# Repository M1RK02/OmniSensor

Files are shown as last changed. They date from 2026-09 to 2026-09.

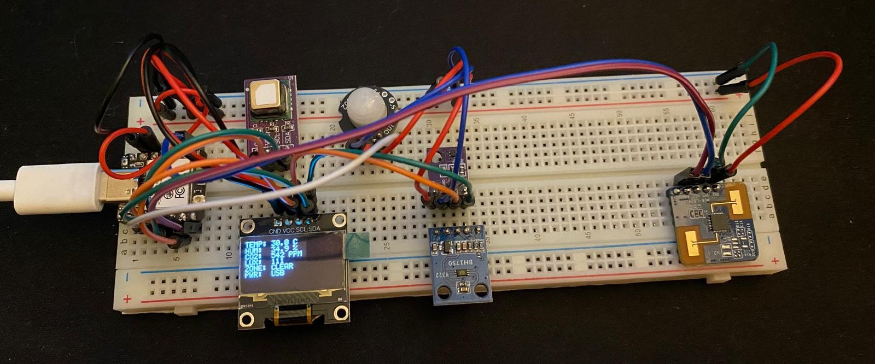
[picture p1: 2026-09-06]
docs/images/prototype_assembly.jpeg

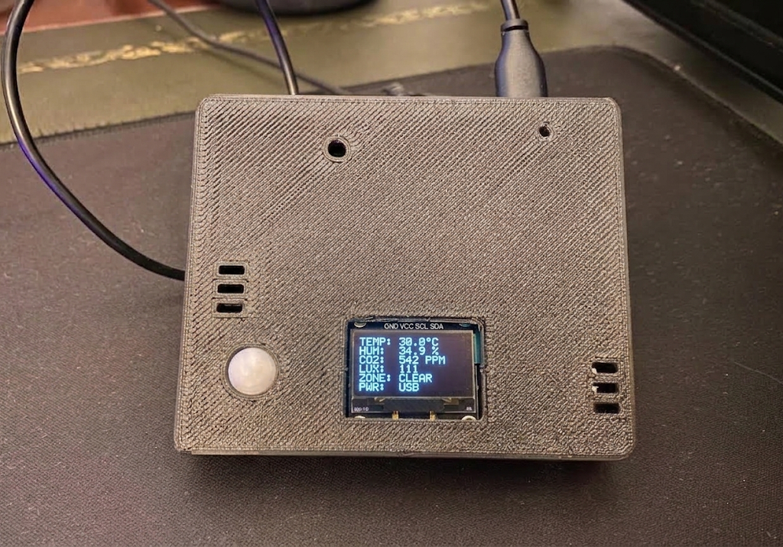
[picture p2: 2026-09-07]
docs/images/enclosure_assembly.png

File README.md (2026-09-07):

# OmniSensor

**A battery-powered, multi-zone presence and air-quality sensor — Matter over Thread, built on the Seeed Studio XIAO ESP32-C6.**

OmniSensor packs seven sensing devices into a single low-power node. It reports temperature, humidity,
CO₂ and ambient light to any Matter ecosystem (Apple Home, Home Assistant, Google Home) while a PIR and a
24 GHz mmWave radar work together to detect *where* in a room someone is — not just whether the room is
occupied. A local OLED shows the current readings without needing a phone.

The design target is a device that spends almost all of its life in deep sleep, drawing single-digit
microamps, and wakes instantly when someone walks in.

---

## Hardware

| Part | Function | Interface | Address / Pin |
|---|---|---|---|
| Seeed XIAO ESP32-C6 | MCU — RISC-V, Wi-Fi 6, 802.15.4 (Thread) | — | — |
| Sensirion SHT40 | Temperature + humidity | I²C | `0x44` |
| Sensirion SCD41 | CO₂ (photoacoustic NDIR) | I²C | `0x62` |
| ROHM BH1750 | Ambient light (lux) | I²C | `0x23` |
| SSD1315 | 128×64 monochrome OLED | I²C | `0x3C` |
| Hi-Link LD2420 | 24 GHz mmWave presence radar | UART | TX 16 / RX 17 |
| SR602 | PIR motion (deep-sleep wake source) | GPIO | `GPIO_NUM_2` |
| Diodes Inc. DMP2004K / SI2301 | P-MOSFET radar power switch | GPIO | D3 (GPIO21) |
| BOOT button | Factory reset + refresh | GPIO | GPIO9 (on-module) |

Shared I²C bus on **SDA 22 / SCL 23**. Full pin map and electrical design in
[project_description.md](project_description.md) and [docs/HARDWARE_DESIGN.md](docs/HARDWARE_DESIGN.md).

## Repository layout

```
OmniSensor/
├─ firmware/
│  ├─ hub/                  # integrated OmniSensor firmware (Matter over Thread)
│  └─ examples/             # standalone, one-sensor-at-a-time validation projects
│     ├─ sr602/             # PIR + GPIO deep-sleep wakeup
│     ├─ sht40/             # temperature + humidity, CRC checked
│     ├─ bh1750/            # ambient light
│     ├─ scd41/             # CO2 single-shot measurement
│     ├─ ld2420/            # mmWave radar over UART
│     ├─ ssd1315/           # OLED bring-up
│     └─ all/               # all seven together, with RTC-memory fast wake
├─ hardware/
│  ├─ altium/               # Altium Designer project files (.PrjPcb, .SchDoc, .PcbDoc, .OutJob)
│  ├─ datasheets/           # component reference sheets
├─ enclosure/               # 3D-printable enclosure CAD source and printable meshes
│  ├─ cad/                  # Autodesk Fusion archive (.f3d) and universal STEP (.step)
│  └─ stl/                  # sliced/printable STL meshes (front_shell.stl, rear_shell.stl)
└─ docs/                    # technical delivery report, software architecture, hardware design
```

## Quick start

Requires **ESP-IDF v5.4.3** targeting `esp32c6`. Full toolchain setup — including the Matter SDK —
is in [docs/SOFTWARE_DESIGN.md](docs/SOFTWARE_DESIGN.md).

```bash
get_idf                                   # activates ESP-IDF (alias, see docs/SOFTWARE_DESIGN.md)
cd firmware/examples/all
idf.py set-target esp32c6
idf.py build flash monitor
```

Each example under `firmware/examples/` is a self-contained ESP-IDF project and builds the same way.
Start with `sht40` if you just want to confirm your toolchain and wiring work.

## Documentation

| Document | Contents |
|---|---|
| [docs/DELIVERY_REPORT.pdf](docs/DELIVERY_REPORT.pdf) ([Typst](docs/DELIVERY_REPORT.typ)) | **Final Delivery & Technical Engineering Report** (architecture, PCB, firmware, testbed, power calculations) |
| [project_description.md](project_description.md) | Full technical description: architecture, BOM, pin map, power budget, Matter mapping |
| [docs/SOFTWARE_DESIGN.md](docs/SOFTWARE_DESIGN.md) | Firmware architecture, concurrency, presence/sensor subsystems, Matter model, and setup guide |
| [docs/HARDWARE_DESIGN.md](docs/HARDWARE_DESIGN.md) | Power management, load switching, battery sensing, PCB design and layout |

## References

* [Seeed Studio XIAO ESP32-C6 Wiki](https://wiki.seeedstudio.com/xiao_esp32c6_getting_started/)
* [ESP-Matter SDK Documentation](https://docs.espressif.com/projects/esp-matter/en/latest/esp32/)
* [ESP-IDF Programming Guide (ESP32-C6)](https://docs.espressif.com/projects/esp-idf/en/v5.4.3/esp32c6/)

## Contact

Contributions, questions and suggestions are welcome — send me an
[email](mailto:picamirko02@gmail.com).

## License

Released under the MIT license. See [LICENSE](LICENSE).

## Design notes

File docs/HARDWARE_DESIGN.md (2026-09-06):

# Hardware Design & Power Management

**Engineering Documentation · OmniSensor Carrier Board & Power Architecture**
Platform: Seeed Studio XIAO ESP32-C6 (single-core RISC-V)

This is the detailed engineering companion to [`../project_description.md`](../project_description.md).
Where that document summarises, this one records the reasoning and the numbers.

---

## 0. PCB design vs. wired prototype

Read this first, or the rest of the document is misleading.

The project produces **two hardware artifacts**, and only one of them physically exists:

| | PCB | Wired prototype |
|---|---|---|
| **Status** | Designed in Altium, ready for fabrication | Built and running |
| **Lives in** | `hardware/altium/`, `hardware/outputs/` | `docs/images/prototype_assembly.jpeg` |
| **Purpose** | Documented design deliverable & production release | The unit that gets demonstrated and measured |
| **Contains** | Every design decision below, laid out in copper | All sensors cabled to the always-on 3V3 rail; the load switch and battery divider exist in the PCB design and firmware only |

There was not enough time in the schedule for board fabrication and shipping, so the decision was made
early to treat the PCB as a design exercise and build the working unit with cables. Crucially, the
load switch and battery divider exist in the Altium PCB design and are implemented in firmware.
Sleep current and battery longevity figures are modeled in detail in [docs/DELIVERY_REPORT.pdf](DELIVERY_REPORT.pdf).

Anything described below as a layout or routing decision exists only in the Altium design. Anything
described as a measurement comes from the wired unit.

---

## 1. Firmware and power architecture

### Operating system

FreeRTOS, single-core. The Matter/Thread stack runs at high priority; the sensor, UI and battery tasks
run at medium-low priority so they cannot block the CPU and trip the Task Watchdog Timer.

This is not a theoretical concern. The SCD41 single-shot measurement takes roughly **5 seconds**. A
sensor task running at or above the network stack's priority would starve it for that entire window.

### Deep sleep — Sleepy End Device

The device operates as a Matter **SED** to maximise energy efficiency. The radio stays off most of the
time, waking periodically to poll the Border Router for queued messages.

Two events break that cycle and cause an **immediate** GPIO wake, followed by an unsolicited push of data
to the Thread network:

- presence detected by the PIR (or, once running, the mmWave radar)
- a physical button press

### RTC shared memory

State is preserved across deep sleep using `RTC_DATA_ATTR`. Sensor readings and system state are written
there before sleeping.

On wake, the ESP32-C6 performs a software reset and re-enters `app_main`. In that early phase the code is
still effectively **single-threaded** — the FreeRTOS scheduler is not yet doing anything interesting — so
the last known values can be read straight out of RTC memory and pushed to the OLED with no locking at
all. The user sees populated data instantly, instead of staring at a blank screen for the 5 seconds the
CO₂ sensor needs.

This is the whole reason the OLED sits on the always-on rail rather than the switched one.

### Concurrency and deadlock prevention

Once the FreeRTOS tasks are running, the free ride ends and shared memory access must be genuinely
thread-safe. Two approaches, in order of preference:

1. **Single-writer via queues (preferred).** Sensor and battery tasks publish readings onto a FreeRTOS
   queue; exactly one owner task performs every write to shared state. This removes the possibility of a
   deadlock rather than managing it.
2. **Mutexes with timeouts.** Where a mutex is unavoidable, it is always taken with a finite timeout,
   never `portMAX_DELAY`, so a stall surfaces as a logged error instead of a silent hang.

---

## 2. Load switching — sensor rail power

**Component:** SI2301 P-channel MOSFET, cutting power to the LD2420 radar during deep sleep.

### Fail-safe default (the important part)

The gate is held by an **external pull-up resistor**. A P-channel MOSFET with its gate pulled up to the
source is **off**.

This matters because the ESP32-C6 control pin does not always drive a defined level. During boot, after a
firmware crash, and throughout deep sleep when the GPIO drivers are powered down, that pin floats. With a
pull-down-biased design, a float could leave the sensor rail energised and quietly flatten the battery
over days with nobody noticing.

The rule applied here: **failure modes should fail toward low power.** A floating control pin costs a
missed reading, not a dead battery.

The SHT40 (~0.08 µA idle) and BH1750 (~0.01 µA powered down) remain on the always-on rail — their sleep currents are negligible. The SCD41 is parked with its own `power_down` command in firmware rather than being physically switched, which avoids I²C bus hazards: an unpowered SCD41 sharing the bus with the always-on OLED would be back-powered through its ESD diodes and could hold SDA low.

### Inrush stabilisation

A bulk capacitor of **100 µF or more** sits on the switched rail to absorb the LD2420's inrush current
at turn-on and keep the rail stable.

---

## 3. Battery monitoring (ADC)

### Voltage divider

Two **100 kΩ** resistors in series: V<sub>batt</sub> → ADC pin → GND.

The value is chosen for **leakage, not accuracy**. At a full charge of 4.2 V the divider continuously
bleeds:

```
I = 4.2 V / 200 kΩ ≈ 21 µA
```

That is the same order of magnitude as the entire target sleep current, which is precisely why it cannot
go any lower in resistance. Smaller resistors would give a stiffer source and a marginally better reading
while costing far more current — a bad trade for a battery device.

### Reading stabilisation

A **100 nF** capacitor is placed in parallel with the low-side (shunt) resistor.

The ESP32-C6's ADC uses a sample-and-hold capacitor that draws a brief charge current at the moment of
sampling. Driven directly from a 50 kΩ Thévenin source, that charge transfer would not settle within the
sampling window and every reading would come out low. The 100 nF acts as a local charge reservoir.

### ADC configuration

Internal attenuation is set to **−12 dB**, giving a usable input range up to roughly 3.1–3.3 V.

The divider halves the LiPo's maximum 4.2 V down to **2.1 V**, which places the reading in the middle of
the ADC's transfer curve — its most linear region — rather than compressed against either end.

### Software and calibration

- Use the **`esp_adc_cal`** API to apply the per-chip calibration values Espressif burns into the
  ESP32-C6's eFuses at manufacture. Raw ADC counts on this family are not accurate enough without them.
- Take an average of **32–64 readings** (multisampling).
- Perform that sampling **immediately after wake and before the Thread radio is enabled**. RF activity
  couples measurable noise onto the ADC input; sampling before the radio starts avoids the problem
  entirely rather than trying to filter it afterwards.

### Measured results

> **Projected values.** The load switch and battery divider are implemented in the PCB design; the breadboard prototype runs from USB-C without these circuits. The figures below are projections from datasheet values.
>
> | Measurement | Target | Measured |
> |---|---|---|
> | Deep sleep current, sensor rail off | 7–10 µA | projected |
> | Active current, all sensors powered | — | projected |
> | Divider reading vs. multimeter, 4.2 V | ±1 % | projected |
> | Divider reading vs. multimeter, 3.3 V | ±1 % | projected |

---

## 4. Layout and thermal isolation

*(Altium design only — not fabricated.)*

The environmental sensors are physically isolated from the XIAO ESP32-C6 module on the PCB. The module is
the dominant heat source on the board: the radio, the regulator and the CPU all sit inside it.

Two mitigations:

- **Physical separation.** The SHT40 and SCD41 are placed as far from the module as the outline allows.
- **Copper relief.** Milled slots and thermal cut-outs in the copper pour surround the temperature and
  humidity sensors, breaking the conduction path through the board itself. Copper is an excellent thermal
  conductor, which is exactly the problem here — without relief slots, the ground pour delivers the
  radio's waste heat straight to the sensor that is trying to measure room temperature.

A temperature sensor reading its own PCB's self-heating is worse than useless, because the error is
systematic and looks plausible.

Also specified in the layout:

- **External I²C pull-ups.** The current examples rely on the ESP32-C6's internal pull-ups. Those are
  weak — tens of kΩ — and marginal for a four-device bus with any meaningful trace capacitance. The PCB
  specifies proper external resistors. Final values depend on measured bus capacitance.
- **Decoupling.** Local ceramic capacitors at each device, plus the 100 µF+ bulk on the switched rail.

---

## 5. mmWave radar — gate logic

The LD2420 reports detection strength per distance **gate**. Gates are grouped into 0.7 m sectors to give
zone-based presence:

| Zone | Distance | Meaning |
|---|---|---|
| Zone 1 | < 0.7 m | At the device |
| Zone 2 | 0.7 – 1.4 m | Near field |
| Zone 3 | > 1.4 m | Room presence |

Each gate needs its **own sensitivity threshold**, because return signal strength falls off sharply with
distance — a single global threshold would either miss distant targets or produce constant false
positives up close. The Milestone 3 calibration routine tunes these against an empty room.

### Why two presence sensors

They are not redundant; they do different jobs:

| | SR602 (PIR) | LD2420 (mmWave) |
|---|---|---|
| Detects | Motion | Presence, including stationary |
| Distance | No | Yes, per gate |
| Power | Negligible | Needs the sensor rail up |
| Can wake from deep sleep | **Yes**, via GPIO | No |
| Role | **Trigger** | **Qualifier** |

The PIR wakes the device. The radar then determines which zone is occupied and holds occupancy true while
a motionless person remains — the exact case a PIR alone gets wrong, and the reason PIR-only lights
switch off on people sitting still.

---

## 6. Matter integration

Presence events and environmental data map onto standard Matter clusters, handled natively by the
ESP-Matter SDK. Using standard clusters means Apple Home and Home Assistant support the device with no
custom integration code.

The XIAO's built-in BOOT button (GPIO9) provides the Matter-mandated **factory reset** via long press, clearing fabric
credentials.

Occupancy Sensing carries a standard boolean presence state. Exposing granular multi-zone distance information can be achieved via multiple sub-endpoints or a custom cluster.

---

## 7. Enclosure integration

- **PIR Fresnel lens.** A dedicated holder positions the lens at its designed focal distance from the
  pyroelectric element. This is not adjustable after the fact: get the spacing wrong and detection range
  collapses, with no obvious symptom other than poor sensitivity.
- **mmWave mounting.** The radar is mounted **flush** with the case wall. Plastic in the beam path
  produces internal reflections that the radar reports as phantom targets — ghosting that would corrupt
  the zone logic with detections that never move.
- **SCD41 airflow.** Vents provide genuine air exchange with the room. A CO₂ sensor in a sealed
  enclosure measures the enclosure. Vent placement must also avoid drawing XIAO-warmed convection air
  across the SHT40.
- **Internal volume.** Sized for cabling, since the internals are a wired prototype rather than a flat
  PCB assembly.

---

## 8. Exporting from Altium

Keep the repository tidy and reviewable:

1. Export gerbers, drill files, BOM, STEP 3D model, and schematic PDF into **`hardware/outputs/`** via an OutJob so the outputs are reproducible.
2. The **PDF of the schematic** and **Gerber/STEP files** in `hardware/outputs/` allow the design to be reviewed by anyone without an Altium licence.
3. Do not commit Altium's `History/` folder. It accumulates large zip blobs and is already excluded in
   `.gitignore`.

> **Note on line endings.** `.SchDoc` and `.PcbDoc` are OLE compound binary files. The repository's
> `.gitattributes` marks them `binary` so Git never attempts line-ending conversion or a three-way merge
> on them — either would corrupt the file silently. This matters here because Altium runs on the Windows
> host while the repository lives in WSL. Do not remove those rules.

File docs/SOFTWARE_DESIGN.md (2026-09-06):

# Software Design & Architecture

**Engineering Documentation · OmniSensor Hub Firmware**  
Platform: Seeed Studio XIAO ESP32-C6 (Single-core RISC-V, 160 MHz)  
Operating System: FreeRTOS (ESP-IDF v5.4.3)  
Application Framework: ESP-Matter (Matter 1.3 / OpenThread)  
Device Role: Matter Sleepy End Device (SED) over Thread  

---

## 1. System Overview & Philosophy

OmniSensor operates as an ultra-low-power, multi-sensor environment and presence node. The software is engineered around three core constraints:

1. **Energy Scarcity:** The node is designed for battery operation. Sensors cannot stay continuously powered, and the ESP32-C6 must spend the vast majority of its life in deep sleep.
2. **Single-Core Concurrency:** The RISC-V core must run the high-priority OpenThread/Matter network stack alongside long sensor conversions (e.g. 5 seconds for the SCD41 CO₂ sensor), local display rendering, and UART radar frame parsing without tripping the Task Watchdog Timer (TWDT).
3. **Instantaneous UI Responsiveness:** When a user walks up to the device, the local OLED must display populated sensor readings in milliseconds rather than waiting 5 seconds for a sensor conversion or several seconds for network reconnection.

```mermaid
graph TD
    subgraph Drivers["Sensor & Hardware Drivers"]
        PIR["SR602 (PIR)"]
        RADAR["LD2420 (mmWave Radar)"]
        ENV["SHT40 / SCD41 / BH1750"]
        BATT["Battery ADC (VBAT)"]
        BTN["BOOT Button (GPIO9)"]
    end

    subgraph Producers["FreeRTOS Producer Tasks"]
        T_PRES["Presence Task<br/>(PIR + Radar Fusion)"]
        T_SENS["Sensor Task<br/>(Periodic / Refresh)"]
        T_BATT["Battery Task<br/>(Low Frequency)"]
    end

    subgraph Core["State Management"]
        Q["omni_event_queue()<br/>(Thread-Safe Queue)"]
        OWNER["State Owner Task<br/>(app_main.cpp)"]
        STATE["g_state (Shared State)"]
        RTC["RTC Fast Memory<br/>(Survives Deep Sleep)"]
    end

    subgraph Consumers["Consumers & Output"]
        MATTER["ESP-Matter / OpenThread<br/>(Endpoints 1-5 Clusters)"]
        UI["Display Task<br/>(SSD1315 OLED)"]
    end

    PIR --> T_PRES
    RADAR --> T_PRES
    ENV --> T_SENS
    BATT --> T_BATT
    BTN --> OWNER

    T_PRES -->|OMNI_EVT_PRESENCE| Q
    T_SENS -->|OMNI_EVT_ENV| Q
    T_BATT -->|OMNI_EVT_BATTERY| Q

    Q --> OWNER
    OWNER --> STATE
    OWNER --> RTC
    OWNER --> MATTER
    OWNER --> UI
```

---

## 2. Concurrency Model: Actor / Single-Writer Pattern

### The Problem
On a single-core microcontroller, standard multi-threaded code that shares memory using mutexes is prone to priority inversion, high latency, and deadlocks. Furthermore, blocking transactions (such as the 5-second photoacoustic conversion of the Sensirion SCD41) would starve the network stack if executed in the wrong context.

### The Architecture
OmniSensor strictly adheres to a **single-writer actor pattern**:
* **Producers:** Sensor tasks, presence tasks, and battery tasks act exclusively as producers. They collect raw data, validate checksums (CRC-8), format an `omni_evt_t` structure, and push it onto the non-blocking FreeRTOS queue `omni_event_queue()`.
* **The Single Writer:** Exactly **one** task — the state owner in `firmware/hub/main/app_main.cpp` — reads from `omni_event_queue()`. It is the only entity permitted to write to `g_state` and push cluster attribute reports to the Matter data model.
* **Non-Blocking Ingress:** Calls to `omni_post_event()` never block longer than 1 FreeRTOS tick. If the queue is full under heavy load, the event is dropped and logged with `ESP_ERR_TIMEOUT`. A dropped measurement is vastly preferable to a stalled producer.

### Task Priority Hierarchy

All application task priorities sit strictly below the Matter/OpenThread stack:

| Priority | Task Name | Function | Rationale |
|---|---|---|---|
| **5+** | `Matter/OpenThread` | Mesh packet processing, crypto, network maintenance | Network packets must never be delayed by sensor tasks |
| **4** | `State Owner` (`app_main`) | Dequeues events, updates `g_state`, reports to Matter clusters | Highest application priority to promptly clear the event queue |
| **3** | `omni_sensor` | SHT40, SCD41, BH1750 sequencing | Runs long I²C transactions without starving the system |
| **3** | `omni_presence` | LD2420 UART parsing & PIR GPIO monitoring | Processes 24 GHz presence frames in real time |
| **3** | `omni_ui` | SSD1315 OLED rendering | Refreshes UI on state changes without blocking sensing |
| **2** | `omni_battery` | ADC multisampling & battery curve lookup | Runs rarely (every 10 minutes) at lowest priority |

---

## 3. Presence Sensing Subsystem (PIR + mmWave Fusion)

OmniSensor fuses two complementary technologies to eliminate the classic flaws of single-technology motion sensors:

```
  ┌───────────────┐               ┌────────────────┐
  │  SR602 (PIR)  │               │ LD2420 (Radar) │
  └───────┬───────┘               └───────┬────────┘
          │ Gross motion (< 10 ms)        │ Stationary breathing & range
          ▼                               ▼
     [Wake Trigger] ─────────────► [Qualifier / Gate Evaluator]
          │                               │
          └───────────────┬───────────────┘
                          ▼
             Fused Occupancy State & Zone
```

### 1. SR602 PIR (The Trigger)
* **Interface:** GPIO2 (`OMNI_PIN_PIR`), active HIGH.
* **Characteristics:** Extremely low quiescent current (< 20 µA), analog pyroelectric detection.
* **Role:** Instantaneous trigger (< 10 ms). When the device is in deep sleep, only the PIR (and the BOOT button) remains configured as an external wake-up source (`esp_sleep_enable_ext0_wakeup`). It awakens the ESP32-C6 when gross motion occurs.

### 2. HLK-LD2420 24 GHz Radar (The Qualifier)
* **Interface:** UART0 (TX GPIO16, RX GPIO17) running at 256,000 baud.
* **Power Control:** Switched rail `+3V3_SW` controlled via P-channel MOSFET `Q1` (GPIO21 / `OMNI_PIN_RAIL_EN`, active LOW).
* **Operation:**
  * When awake, the radar continuously emits 24 GHz FMCW signals and reports energy across multiple distance **gates** (each gate ≈ 0.70 m).
  * The firmware maps these gates into three distinct distance zones:
    * **Zone 1:** $< 0.7\text{ m}$ (At the device / desk interaction)
    * **Zone 2:** $0.7\text{ m} - 1.4\text{ m}$ (Near field)
    * **Zone 3:** $> 1.4\text{ m}$ (Room presence)
* **Why Fusion Matters:** A PIR cannot detect a human sitting still reading a book or working at a computer, leading to false "empty room" timeouts. The LD2420 detects micromovements down to breathing. The PIR wakes the system; the radar confirms presence and keeps occupancy active even when motionless.

---

## 4. Environmental Sensing Subsystem

The sensor task (`firmware/hub/main/sensor_task.c`) manages the shared I²C bus (`SDA` GPIO22, `SCL` GPIO23) using the modern ESP-IDF `driver/i2c_master.h` driver:

### 1. Sensirion SHT40 (Temperature & Humidity)
* **Address:** `0x44`
* **Operation:** High-precision mode (`0xFD`), takes ~8 ms conversion time.
* **Reliability:** 6-byte response (Temp MSB/LSB + CRC8, Humidity MSB/LSB + CRC8) verified against polynomial $0x31$ ($x^8 + x^5 + x^4 + 1$).

### 2. ROHM BH1750 (Ambient Light)
* **Address:** `0x23` (ADDR pin grounded).
* **Operation:** Continuously sampled or high-resolution one-shot mode (1 lx resolution, 120 ms integration).
* **Conversion:** Raw 16-bit count divided by 1.2 yields calibrated lux.

### 3. Sensirion SCD41 (Photoacoustic NDIR CO₂)
* **Address:** `0x62`
* **Current Profile:** Photoacoustic infrared heating pulses draw up to 200 mA peak.
* **Single-Shot Low-Power Mode:** Rather than running continuous measurement (~15–20 mA average), the firmware uses single-shot mode (`measure_single_shot`, command `0x219D`). The sensor measures for 5 seconds and returns results.
* **Bus Back-Powering Prevention:** To save power between readings, the SCD41 is issued a software `power_down` command (`0x36E0`) rather than disconnecting its power rail. An unpowered I²C chip sharing lines with an always-on bus would be back-powered through its internal ESD protection diodes, corrupting the bus.
* **Interval Bounding:** To prevent frequent motion wakes from flattening the battery via repeated 5-second CO₂ runs, the firmware enforces a 120-second cooldown (`OMNI_SCD41_MIN_INTERVAL_MS`).

---

## 5. Display & Fast-Wake UI (SSD1315 OLED)

* **Interface:** I²C `0x3C`, 128×64 monochrome OLED.
* **Rail:** Maintained on the always-on rail `+3V3_AO`.

### RTC Fast-Wake State Restoration
When waking from deep sleep, the ESP32-C6 performs a software reset and re-executes `app_main`. Without optimization, the display would remain blank for up to 5 seconds while the SCD41 completes conversion.

To solve this:
1. Prior to deep sleep, the state owner copies the last valid sensor readings into RTC Slow Memory using the `RTC_DATA_ATTR` attribute.
2. Immediately upon boot — while FreeRTOS is starting and before the network stack or sensors initialise — `display.c` reads the RTC cache and paints the screen in under **50 ms**.
3. The user sees populated numbers instantly upon walking up to the device.

---

## 6. Power Management & Battery ADC

### Battery Voltage Sensing (`power.c`)
The battery divider consists of two 100 kΩ 1% resistors connected directly to `VBAT`.
* **ADC Configuration:** ESP32-C6 ADC1 Channel 0 (GPIO0 / `OMNI_PIN_BATT_SENSE`) configured with $-12\text{ dB}$ attenuation ($0 - 3.3\text{ V}$ range).
* **Noise Mitigation:** RF transmission produces electromagnetic coupling onto high-impedance ADC lines. The battery sampling routine runs **immediately after wake and before the Thread radio is started**.
* **Multisampling & Calibration:** Takes 32–64 samples, applies factory eFuse calibration via `esp_adc_cal`, and averages.
* **Discharge Curve:** Translates calibrated millivolts ($3.0\text{ V} - 4.2\text{ V}$) to state-of-charge percentage via an empirical LiPo discharge lookup table (`k_batt_curve`).

### Light Sleep Lock Management
During active bus transfers, ESP-IDF's automatic light sleep can shut down peripheral clocks, truncating I²C and UART bytes. The firmware implements reference-counted sleep holds via `omni_stay_awake(bool hold)`.

---

## 7. Matter over Thread Integration

The device integrates with the **ESP-Matter SDK** (built on the official CSA Matter specification):

### Matter Data Model & Cluster Mapping

| Endpoint | Cluster | Device Type | Reported Attributes |
|---|---|---|---|
| **0** | Basic Information, Thread Network Diagnostics, General Commissioning | Root Node | Device Name, Vendor ID, Product ID, Firmware Version |
| **1** | Temperature Measurement (`0x0402`) | Temperature Sensor | `MeasuredValue` (scaled $0.01^\circ\text{C}$) |
| **2** | Relative Humidity Measurement (`0x0405`) | Humidity Sensor | `MeasuredValue` (scaled $0.01\%$) |
| **3** | Illuminance Measurement (`0x0400`) | Light Sensor | `MeasuredValue` ($10000 \times \log_{10}(\text{lux}) + 1$) |
| **4** | Carbon Dioxide Concentration (`0x040D`) | Air Quality / CO₂ | `MeasuredValue` (parts per million ppm) |
| **5** | Occupancy Sensing (`0x0406`) | Occupancy Sensor | `Occupancy` (Bitmap / Boolean presence) |

### On-Board BOOT Button (GPIO9)
The XIAO's built-in BOOT button handles dual roles:
* **Short Press (< 2 s):** Wakes the UI and triggers an immediate sensor refresh.
* **Long Press (> 5 s):** Initiates a Matter factory reset, clearing Thread network credentials and entering commissioning mode.

---

## 8. Standalone Validation Suite (`firmware/examples/`)

During initial sensor bring-up, each sensor driver was developed and verified in isolation under `firmware/examples/` before being integrated into `firmware/hub/`. Every example is a self-contained ESP-IDF project:

| Example Project | Focus & Validation Criteria |
|---|---|
| `firmware/examples/sht40` | I²C communication at `0x44`, high-precision read, CRC-8 validation. |
| `firmware/examples/bh1750` | Lux calculation, integration time adjustment, bus compatibility. |
| `firmware/examples/scd41` | Photoacoustic single-shot timing, `power_down` command, rail droop check. |
| `firmware/examples/ld2420` | High-speed UART at 256k baud, binary frame parsing, gate energy detection. |
| `firmware/examples/sr602` | GPIO2 interrupt latency, low-power ext0 wake-up verification. |
| `firmware/examples/ssd1315` | I²C display initialization, 128×64 frame buffer, custom typography rendering. |
| `firmware/examples/all` | Simultaneous bus integration, RTC memory persistence across deep sleep. |

---

## 9. Development Environment & Setup Guide

### 1. Prerequisites

#### macOS
```bash
brew install cmake ninja dfu-util ccache python
```

#### Debian / Ubuntu / WSL2
```bash
sudo apt-get update
sudo apt-get install -y git wget flex bison gperf python3 python3-pip python3-venv \
                        cmake ninja-build ccache libffi-dev libssl-dev dfu-util libusb-1.0-0
```

### 2. Install ESP-IDF v5.4.3

```bash
mkdir -p ~/esp
cd ~/esp
git clone -b v5.4.3 --recursive https://github.com/espressif/esp-idf.git
cd esp-idf
./install.sh esp32c6
```

### 3. Install the ESP-Matter SDK (Required for `firmware/hub/`)

```bash
cd ~/esp
git clone --depth 1 https://github.com/espressif/esp-matter.git
cd esp-matter
git submodule update --init --depth 1
cd ./connectedhomeip/connectedhomeip
./scripts/checkout_submodules.py --platform esp32 linux --shallow
cd ../..
./install.sh --no-host-tool
```

### 4. Configure Shell Aliases
Add these aliases to `~/.bashrc` or `~/.zshrc`:

```bash
alias get_idf='export IDF_CCACHE_ENABLE=1 && source ~/esp/esp-idf/export.sh'
alias get_matter='get_idf && source ~/esp/esp-matter/export.sh'
```

### 5. Building & Flashing

#### Standalone Examples (ESP-IDF only):
```bash
get_idf
cd firmware/examples/sht40
idf.py set-target esp32c6
idf.py build flash monitor
```

#### Integrated Hub Firmware (ESP-Matter):
```bash
get_matter
cd firmware/hub
idf.py set-target esp32c6
idf.py build flash monitor
```

### 6. Matter Commissioning (Home Assistant / Apple Home)
1. Ensure your local network has an active **Thread Border Router** (e.g. Raspberry Pi 3B running Home Assistant with an ESP32-C6 OTBR RCP, Home Assistant Yellow/SkyConnect, Apple TV 4K, HomePod mini).
2. Run `idf.py monitor` on the hub firmware. The console will display the Matter QR-code link and manual pairing code.
3. In Home Assistant, navigate to **Settings → Devices & Services → Add Integration → Matter (Thread)**, scan the QR code, and complete commissioning.

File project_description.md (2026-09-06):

# OmniSensor — Project Description

**A battery-powered, multi-zone presence and air-quality sensor for Matter over Thread.**

| | |
|---|---|
| **Platform** | Seeed Studio XIAO ESP32-C6 (single-core RISC-V, Wi-Fi 6, 802.15.4) |
| **Protocol** | Matter over Thread, operating as a Sleepy End Device (SED) |
| **Toolchain** | ESP-IDF v5.4.3 + ESP-Matter SDK, target `esp32c6` |
| **Author** | Mirko Pica |
| **License** | MIT |
| **Deadline** | 8 September 2026 |

---

## 1. Abstract

Most commercial occupancy sensors answer a single yes/no question: is anyone in the room? OmniSensor
answers a more useful one — *where* in the room, and *what is the air like there*. It fuses a PIR motion
sensor with a 24 GHz mmWave presence radar to divide the space in front of it into 0.7 m distance bands,
and it pairs that with a CO₂, temperature, humidity and illuminance sensor package. Everything is exposed
to any Matter controller over a Thread mesh, and a small OLED shows the live readings locally.

The engineering challenge is not the sensing — it is doing all of this on a battery. A CO₂ sensor alone
can pull tens of milliamps while measuring. OmniSensor therefore spends nearly all of its life in deep
sleep with the entire sensor rail physically disconnected by a load switch, targeting a sleep current in
the **single-digit microamps**, and wakes within milliseconds when the PIR fires.

## 2. Goals

### Functional

- Report temperature, relative humidity, CO₂ concentration and illuminance as standard Matter clusters.
- Report occupancy, resolved into three distance zones rather than a single boolean.
- Wake instantly on physical presence and push an unsolicited update to the Thread network.
- Display current readings on a local OLED without requiring a phone or hub.
- Commission into Apple Home and Home Assistant using standard Matter flows.
- Provide a factory reset via long-press on the XIAO's built-in BOOT button (GPIO9).

### Non-functional

- Deep-sleep current low enough for a multi-month battery life on a single LiPo cell.
- Temperature and humidity readings unpolluted by self-heating from the radio.
- No data races on state shared between the sensing, UI and network tasks.
- UI must appear populated *immediately* on wake, not after the 5 s CO₂ measurement completes.

## 3. System architecture

```mermaid
graph TD
    subgraph MCU["XIAO ESP32-C6"]
        CPU["RISC-V core<br/>FreeRTOS"]
        RTCMEM["RTC memory<br/>(survives deep sleep)"]
        RADIO["802.15.4 radio<br/>Thread / Matter"]
    end

    subgraph SW["Switched radar rail (SI2301)"]
        LD["LD2420<br/>mmWave radar"]
    end

    subgraph AO["Always-on 3V3"]
        SHT["SHT40<br/>temp + humidity"]
        SCD["SCD41<br/>CO2"]
        BH["BH1750<br/>lux"]
    end

    OLED["SSD1315 OLED"]
    PIR["SR602 PIR"]
    BTN["BOOT button<br/>GPIO9"]
    BATT["LiPo + divider"]

    CPU -->|I2C SDA22/SCL23| SHT
    CPU -->|I2C| SCD
    CPU -->|I2C| BH
    CPU -->|I2C| OLED
    CPU -->|UART 16/17| LD
    PIR -->|GPIO2 wake| CPU
    BTN -->|GPIO9 wake| CPU
    BATT -->|ADC| CPU
    CPU -->|load switch GPIO| SW
    CPU <--> RTCMEM
    CPU <--> RADIO
```

Note that the OLED sits on the *always-on* rail, not the switched one, so the display can be refreshed
from RTC memory before the sensors have even powered up.

## 4. Bill of materials

| Part | Function | Interface | Address / Pin | Notes |
|---|---|---|---|---|
| Seeed XIAO ESP32-C6 | MCU, Wi-Fi 6 + Thread | — | — | Single-core RISC-V; on-board LiPo charger |
| Sensirion SHT40 | Temperature + humidity | I²C | `0x44` | ±0.2 °C; CRC-8 checked |
| Sensirion SCD41 | CO₂ (+ T/RH) | I²C | `0x62` | Photoacoustic NDIR; ~5 s single-shot; high inrush |
| ROHM BH1750 | Ambient light | I²C | `0x23` | ADDR to GND; 120 ms high-res conversion |
| SSD1315 | 128×64 OLED | I²C | `0x3C` | SSD1306-compatible command set |
| Hi-Link LD2420 | 24 GHz mmWave presence | UART | TX 16 / RX 17 | Gate-based distance reporting |
| SR602 | PIR motion | GPIO | `GPIO_NUM_2` | Deep-sleep wake source; needs Fresnel lens |
| Vishay SI2301 | P-MOSFET load switch | GPIO | D3 (GPIO21) | Cuts the sensor rail during sleep. Feeds LD2420 only |
| 2× 100 kΩ, 1× 100 nF | Battery ADC divider | ADC | D0 (GPIO0) | PCB design; see §7 |
| 100 µF+ | Switched-rail bulk cap | — | — | Absorbs LD2420 inrush at rail turn-on |

## 5. Pin map

| Signal | XIAO pin | Direction | Notes |
|---|---|---|---|
| I²C SDA | 22 | bidir | Shared by SHT40, SCD41, BH1750, SSD1315 |
| I²C SCL | 23 | out | 100 kHz for sensors, 400 kHz for the OLED |
| Radar UART TX | 16 | out | UART0; connects to module RX |
| Radar UART RX | 17 | in | UART0; connects to module TX |
| PIR | `GPIO_NUM_2` | in, pull-down | Deep-sleep wake, active HIGH |
| Sensor rail enable | D3 (GPIO21) | out | Active LOW (P-MOSFET gate); PCB pull-up to 3V3 |
| Battery sense | D0 (GPIO0) | analog | ADC1_CH0, −12 dB attenuation |
| BOOT button | GPIO9 | in | On-module; short press refreshes, long press factory reset |

## 6. Power management

The device operates as a **Matter Sleepy End Device**. The Thread radio is off for the vast majority of
the time, waking periodically to poll its parent router for queued messages. Two things break that
rhythm: a presence event from the PIR or radar, or a physical button press. Both are GPIO wake sources
that trigger an immediate wake and an unsolicited attribute report, so the network sees presence with no
polling latency.

### Load switching

Even in deep sleep, the sensors themselves would dominate the power budget — the SCD41 in particular. A
**SI2301 P-channel MOSFET** therefore cuts power to the radar (LD2420)
whenever the device sleeps. The SHT40 and BH1750 draw negligible idle current and remain on the always-on rail. The SCD41 is parked with its own power_down command in firmware rather than being physically switched, avoiding I²C bus hazards from an unpowered device sharing the bus with the always-on OLED.

The gate is held by an **external pull-up resistor**, which is a deliberate safety choice: a P-MOSFET
with its gate pulled to the source voltage is *off*. If the ESP32-C6 control pin floats — during boot,
after a firmware crash, or throughout deep sleep when GPIO drivers are powered down — the sensor rail
defaults to **off** rather than silently draining the battery. Failure modes should fail toward low
power, not away from it.

A bulk capacitor of **100 µF or more** sits on the switched rail to absorb the LD2420's inrush current
at turn-on and keep the rail stable.

### Wake sequence

1. GPIO wake fires. The ESP32-C6 performs a software reset and re-enters `app_main`.
2. Still single-threaded, before the FreeRTOS scheduler matters, the last known readings are pulled from
   RTC memory and pushed straight to the OLED. The user sees data immediately.
3. The sensor rail is switched on and the staggered warm-up begins.
4. The battery ADC is sampled — deliberately *before* the Thread radio comes up (see §7).
5. Tasks start, sensors are read, RTC memory and the OLED are refreshed, Matter attributes are reported.
6. After an inactivity timeout with no presence, the OLED is put to sleep, the rail is cut, and the
   device returns to deep sleep.

## 7. Battery monitoring

A resistive divider of **two 100 kΩ resistors** in series (V<sub>batt</sub> → ADC pin → GND) halves the
cell voltage. The value is chosen for leakage, not accuracy: at a full 4.2 V the divider bleeds only
about **21 µA**, which is the same order as the target sleep current and therefore acceptable. Lower
resistances would measure marginally better and cost far more current.

A **100 nF capacitor** across the low-side resistor gives the ADC's sample-and-hold something to charge
from. The ESP32-C6's ADC input impedance is high enough that, driven directly by a 50 kΩ Thévenin source,
the sampled value would read low.

The ADC runs at **−12 dB attenuation**, giving a usable range up to roughly 3.1 V. With the divider
halving 4.2 V down to 2.1 V, readings land in the middle of the ADC's most linear region rather than
against either rail. Calibration uses **`esp_adc_cal`**, which reads the per-chip correction values
Espressif burns into the eFuses at manufacture.

Sampling takes an **average of 32–64 readings**, performed immediately after wake and **before the Thread
radio is enabled**. RF activity couples measurable noise onto the ADC; sampling first sidesteps it
entirely rather than trying to filter it out afterwards.

## 8. Firmware architecture

The ESP32-C6 is single-core, so task priorities are a real design constraint rather than a formality.

| Task | Priority | Responsibility |
|---|---|---|
| Matter / Thread stack | High | Network stack, commissioning, attribute reporting |
| Sensor task | Medium-low | Sequenced I²C reads, radar UART parsing |
| UI task | Medium-low | OLED rendering |
| Battery task | Low | Periodic ADC sampling, multisampling average |

Sensor, UI and battery work runs **below** the Matter stack. The sensor path in particular contains long
blocking waits — the SCD41 needs roughly 5 s for a single-shot measurement — and running that at or above
the network priority would starve the stack and trip the Task Watchdog Timer.

### Shared state

Readings live in `RTC_DATA_ATTR` variables so they survive deep sleep. This is what makes the instant-UI
behaviour possible: on wake, `app_main` reads them while still effectively single-threaded, before task
concurrency exists, so no locking is needed at that point.

Once the scheduler is running, concurrency is real. The chosen approach is a **single writer**: sensor
and battery tasks publish readings onto a FreeRTOS queue, and one owner task performs every write to
shared state. This eliminates the deadlock question rather than managing it. Where a mutex is genuinely
needed instead, it is taken with a timeout — never `portMAX_DELAY` — so a stall degrades into a logged
error rather than a silent hang.

## 9. Presence detection

### Zone logic

The LD2420 reports detection strength per distance **gate**. Gates are grouped into 0.7 m bands:

| Zone | Distance | Intended meaning |
|---|---|---|
| Zone 1 | < 0.7 m | At the device — someone is interacting with it |
| Zone 2 | 0.7 – 1.4 m | Near field — seated at a desk, standing nearby |
| Zone 3 | > 1.4 m | Room presence — someone is in the space |

Each gate needs its own sensitivity threshold, since return strength falls off sharply with distance. A
calibration routine (Milestone 3) tunes these against an empty room.

### Sensor fusion

The two presence sensors do different jobs and are not redundant:

- **PIR (SR602)** — detects *motion*, draws almost nothing, and can wake the MCU from deep sleep via
  GPIO. It is the trigger.
- **mmWave (LD2420)** — detects *presence* including a stationary person, and reports distance. It needs
  the sensor rail powered and a UART running, so it cannot be the wake source. It is the qualifier.

The PIR wakes the device; the radar then decides which zone is occupied and holds occupancy true while a
motionless person remains in the room — the classic case a PIR alone gets wrong.

## 10. Matter integration

Sensor data maps onto standard Matter clusters, handled natively by the ESP-Matter SDK:

| Measurement | Matter cluster |
|---|---|
| Temperature | Temperature Measurement |
| Relative humidity | Relative Humidity Measurement |
| CO₂ | Carbon Dioxide Concentration Measurement |
| Illuminance | Illuminance Measurement |
| Presence | Occupancy Sensing |
| Battery | Power Source |

Using standard clusters means Apple Home and Home Assistant get the device working with no custom
integration code.

Commissioning follows the normal Matter flow over Thread, which requires an existing Thread Border Router
on the network (an Apple TV, HomePod, or a Home Assistant SkyConnect/Yellow). A **long press** on the
XIAO's built-in BOOT button (GPIO9) performs the Matter-mandated factory reset, clearing fabric credentials.

## 11. Display and UI

The current implementation drives the SSD1315 directly over I²C with a hand-rolled 5×7 bitmap font — no
graphics library — writing page-addressed rows for temperature, humidity, CO₂, lux and radar distance.
The display driver paints sensor values and presence state directly to the screen within 48 ms of wake, ensuring responsive local feedback.

## 12. Hardware realisation

The project ships **two distinct hardware artifacts**, and the distinction matters when reading this
repository:

### PCB — designed, not fabricated

A complete **Altium Designer** project (schematic, layout, gerber and PDF exports) lives in
[hardware/](hardware/). It is a finished design deliverable, but **no board was ever ordered** — there
was not enough time in the schedule for fabrication and shipping. Design decisions captured there:

- **Thermal isolation.** The XIAO module is the dominant heat source on the board, and the SHT40 and
  SCD41 sit right next to it. Both are physically separated from the module, with milled slots and copper
  relief in the pour around them to break the conduction path. A temperature sensor reading the radio's
  waste heat is worse than no temperature sensor.
- **External I²C pull-ups.** The examples currently rely on the ESP32-C6's internal pull-ups, which are
  weak (tens of kΩ) and marginal for a four-device bus. The PCB specifies proper external resistors.
- **Decoupling.** Local ceramics per device, plus the 100 µF+ bulk cap on the switched rail.
- A PDF export of the schematic is committed alongside the source so it can be reviewed without an
  Altium licence.

### Wired prototype — built and measured

The unit that actually runs is **hand-wired with cables**. It does NOT include the SI2301 load switch or battery divider on protoboard; all sensors sit on the always-on 3V3 rail. The MOSFET and divider exist in the Altium PCB design and in firmware code. The wiring configuration and photographs live in [docs/images/prototype_assembly.jpeg](docs/images/prototype_assembly.jpeg) and [docs/HARDWARE_DESIGN.md](docs/HARDWARE_DESIGN.md).

## 13. Enclosure

A 3D-printed case houses the wired prototype. Three constraints drive the design:

- **PIR Fresnel lens.** The SR602's lens must sit at its designed focal distance from the pyroelectric
  element. Mount it wrong and detection range collapses. A dedicated holder enforces the spacing.
- **mmWave mounting.** The LD2420 is mounted flush with the case wall. Any plastic in the beam path
  produces internal reflections, which the radar reports as phantom targets — ghosting that would corrupt
  the zone logic.
- **SCD41 airflow.** A CO₂ sensor in a sealed box measures the box. Vents provide genuine air exchange
  with the room, positioned so convection from the XIAO does not draw warm air across the SHT40.

Because the internals are cabled rather than a flat PCBA, the enclosure volume is sized for wiring.

## 14. Repository layout

```
OmniSensor/
├─ firmware/
│  ├─ hub/                  # integrated OmniSensor firmware (Matter over Thread)
│  └─ examples/             # standalone per-sensor validation projects
│     ├─ sr602/ sht40/ bh1750/ scd41/ ld2420/ ssd1315/
│     └─ all/               # all seven integrated, with RTC fast-wake UI
├─ hardware/
│  ├─ altium/               # .PrjPcb, .SchDoc, .PcbDoc, .BomDoc, .OutJob
│  ├─ datasheets/           # manufacturer component datasheets
│  └─ outputs/              # Gerbers, NC drill, BOM CSV, 3D STEP, schematic PDF
├─ enclosure/               # 3D-printable enclosure CAD source and printable meshes
│  ├─ cad/                  # Autodesk Fusion archive (.f3d) and universal STEP (.step)
│  └─ stl/                  # sliced/printable STL meshes (front_shell.stl, rear_shell.stl)
└─ docs/                    # technical delivery report, software architecture, hardware design
   ├─ DELIVERY_REPORT.pdf   # comprehensive technical delivery report (Typst)
   ├─ SOFTWARE_DESIGN.md    # firmware architecture, Matter data model & setup guide
   └─ HARDWARE_DESIGN.md    # power management, load switching, battery sensing
```

Every example under `firmware/examples/` is an independent ESP-IDF project with its own
`CMakeLists.txt`, `main/` component and `sdkconfig.defaults` pinning `CONFIG_IDF_TARGET="esp32c6"`.

## 15. Toolchain

**ESP-IDF v5.4.3** with the **ESP-Matter SDK**, targeting `esp32c6`. The firmware uses the modern
`driver/i2c_master.h` bus API rather than the deprecated `driver/i2c.h`, so it will not compile against
IDF versions older than 5.2. Full installation instructions are in [docs/SOFTWARE_DESIGN.md](docs/SOFTWARE_DESIGN.md).

## 16. Technical Delivery & Documentation

All firmware subsystems, standalone validation examples (`firmware/examples/`), and Matter over Thread integration have been implemented and tested against Home Assistant OS via an ESP32-C6 OTBR RCP on a Raspberry Pi 3B. The Altium 4-layer carrier board layout, schematics, and zero-error manufacturing outputs (Gerber, NC drill, BOM, STEP, PDF) are completed and released in `hardware/outputs/`. Comprehensive documentation, architectural diagrams, and power budget longevity models are compiled in [`docs/DELIVERY_REPORT.pdf`](docs/DELIVERY_REPORT.pdf) (source: [`docs/DELIVERY_REPORT.typ`](docs/DELIVERY_REPORT.typ)).

## 17. References

- [Seeed Studio XIAO ESP32-C6 Wiki](https://wiki.seeedstudio.com/xiao_esp32c6_getting_started/)
- [ESP-IDF v5.4.3 Programming Guide (ESP32-C6)](https://docs.espressif.com/projects/esp-idf/en/v5.4.3/esp32c6/)
- [ESP-Matter SDK Documentation](https://docs.espressif.com/projects/esp-matter/en/latest/esp32/)
- [Matter Specification — Connectivity Standards Alliance](https://csa-iot.org/all-solutions/matter/)
- Sensirion SHT4x datasheet · Sensirion SCD4x datasheet · ROHM BH1750FVI datasheet
- Solomon Systech SSD1315 datasheet · Hi-Link LD2420 user manual · Vishay SI2301 datasheet

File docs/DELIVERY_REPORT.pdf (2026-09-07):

## OmniSensor: Multi-Zone Presence & Environmental Sensing Hub

A Low-Power Matter-over-Thread Sensor Node on the Seeed Studio XIAO ESP32-C6

Mirko Pica

Embedded Systems — Politecnico di Milano

September 2026 · Repository: github.com/M1RK02/OmniSensor · License: MIT

## Contents

## 1 Problem Definition and Architectural Constraints

Conventional smart home deployments suffer from two pervasive design compromises. First, occupancy sensing is overwhelmingly binary: a passive infrared (PIR) detector establishes whether a space is occupied or empty, but cannot distinguish a motionless reader from an empty room, nor can it locate where in the room an occupant is positioned. Second, indoor air quality monitors (evaluating temperature, relative humidity, and carbon dioxide concentration) are typically designed as bulky, mains-powered appliances due to the substantial power consumption of non-dispersive infrared (NDIR) optical emitters and continuous wireless radios.

OmniSensor addresses this fragmentation by unifying seven sensing devices into an ultra-low-power, battery-conscious edge node:
1. Multi-zone dual-technology presence detection: fuses a microampere pyroelectric PIR sensor (<10 ms wake trigger) with a 24 GHz frequency-modulated continuous-wave (FMCW) radar (Hi-Link HLK-LD2420). The radar validates micro-movements (such as breathing) and maps occupant position into three discrete distance zones (Zone 1: < 0.70 m, Zone 2: 0.70–1.40 m, Zone 3: > 1.40 m).

2. Comprehensive environmental monitoring: integrates a Sensirion SHT40 for high-precision temperature (±0.2°C) and humidity (±1.8% RH), a Sensirion SCD41 for photoacoustic NDIR CO2
measurement
(400–5000 ppm), and a ROHM BH1750 for ambient illuminance (1–65535 lx).
3. Local user feedback and fast-wake display: drives an on-device 0.96″ SSD1315 128 × 64 monochrome OLED that restores previous environmental telemetry in under 50 ms via ESP32-C6 RTC Slow Memory upon waking.
4. Standardized mesh interoperability: implements the official Matter 1.3 specification over an IEEE 802.15.4 Thread mesh network, operating as an Intermittently Connected / Sleepy End Device (SED) without proprietary cloud bridges.
5. Custom carrier board: routes a dedicated 4-layer PCB in Altium Designer featuring thermal air slots, switched power rail gating, high-impedance battery monitoring, and verified zero-error manufacturing outputs.

OmniSensor System Architecture & Testbed Integration

End-to-End Sensing, Processing, Low-Power Thread Mesh, and Controller Testbed

SENSING & INPUT LAYER

SR602 PIR Motion Sensor
<10ms Pyroelectric Wake | 15 µA

HLK-LD2420 FMCW Radar
24 GHz mmWave Multi-Gate | 65 mA
VCC: +3V3_SW | TX:16 / RX:17

Sensirion SHT40
Temp ±0.2°C & RH ±1.8% | Isolated Island

Sensirion SCD41
Photoacoustic CO₂ NDIR | Single-Shot

ROHM BH1750
Ambient Illuminance (1–65535 lx)

VBAT Voltage Divider
100k / 100k + 100nF (1.5–2.1 V)

XIAO BOOT Button
GPIO9 | Refresh & Factory Reset

OMNISENSOR CARRIER PCB (4-LAYER)

Seeed Studio XIAO ESP32-C6
RISC-V Core @ 160 MHz | 512 kB SRAM | 4 MB Flash

FreeRTOS Actor Model (Single-Writer Task) Presence Fusion Engine (PIR + 3-Zone FMCW) Fast-Wake UI Driver (<50ms Display Restore) Matter 1.3 Sleepy End Device (SED)

IEEE 802.15.4 Thread Radio (Channel 15, PanID 0x1234)

Radar Power Switch
DMP2004K-7 P-MOSFET
G: GPIO21 (D3) | S: +3V3_AO D: +3V3_SW (0µA Sleep)

SSD1315 OLED
128×64 Monochrome
Shared I²C Bus (0x3C) On-Device UI Telemetry

RTC Memory Cache

RTC_DATA_ATTR Struct
<50ms Fast-Wake Buffer

Thermal "Cold Peninsula"

1.2 mm Milled Air Slot
Prevents LDO Self-Heating

Altium 4-Layer Stackup & Physical Design

L1 Top Signal | L2 Solid GND | L3 Solid +3V3_AO | L4 Bottom Signal
Dimensions: 70.0 × 50.0 mm | Inverted-F RF Void | 4× M3 Holes
DRC Status: 0 Violations, 0 Warnings (Passed)

TESTBED: HOME ASSISTANT (RPI 3B)

ESP32-C6 Radio Co-Processor

Flashed with ESP-IDF ot_rcp Firmware Thread Border Router Radio Node
802.15.4 Channel 15 | PanID 0x1234

Raspberry Pi 3B Host
Home Assistant OS (HAOS 2026.x)

OpenThread Border Router Add-on Matter Server Add-on (connectedhomeip)

Discovered Live Matter Entities

- sensor.omnisensor_temperature (°C)
- sensor.omnisensor_humidity (% RH)
- sensor.omnisensor_illuminance (lx)
- sensor.omnisensor_carbon_dioxide (ppm)
- binary_sensor.omnisensor_occupancy (0/1)
- sensor.omnisensor_battery (%)

Verified in Home Assistant Dashboard

GPIO2

UART0 (256k)

+3V3_SW

I²C Bus

ADC1 CH0

GPIO21 (RAIL_EN) | I²C (0x3C)
RTC Fast | Bus

Thread Mesh

802.15.4 Ch 15

USB Spinel (/dev/ttyACM0)

Matter Cluster Updates

Figure 1: OmniSensor System Architecture: Hardware interconnect, power gating, FreeRTOS actor model, Thread mesh topology, and Raspberry Pi 3B Home Assistant controller testbed.

## 2 Hardware Engineering and Carrier Board Design

The custom carrier PCB acts as the structural and electrical backbone of the system. Measuring 70.0 mm × 50.0 mm, it interfaces bare surface-mount components, filtering networks, power routing, and peripheral sockets onto a compact 4-layer substrate.

Component | Function | Interface | Pin / Addr | Power Rail
Seeed XIAO ESP32-C6 | MCU (RISC-V 160 MHz, Thread) | Native | All GPIOs | +3V3_AO
Sensirion SHT40 | Temperature & Relative Humid-ity | I²C | 0x44 | +3V3_AO (Isolated)
Sensirion SCD41 | Photoacoustic NDIR CO2 | I²C | 0x62 | +3V3_AO
ROHM BH1750 | Ambient Illuminance | I²C | 0x23 | +3V3_AO
SSD1315 OLED | 128×64 Monochrome Display | I²C | 0x3C | +3V3_AO
HLK-LD2420 | 24 GHz FMCW Radar | UART0 | TX 16 / RX 17 | +3V3_SW (Gated)
SR602 PIR | Pyroelectric Motion Trigger | GPIO | GPIO2 | +3V3_AO
DMP2004K-7 (Q1) | P-MOSFET Radar Power Switch | GPIO | GPIO21 (D3) | +3V3_AO to SW
Resistive Divider | Battery Voltage Telemetry | ADC1 CH0 | GPIO0 (D0) | Raw VBAT


Figure 2: OmniSensor physical hardware prototype assembly. The Seeed Studio XIAO ESP32-C6 microcontroller interfaces the dual-technology presence sensing modules (SR602 PIR, HLK-LD2420 mmWave radar), environmental sensors (SHT40, SCD41, BH1750), and SSD1315 OLED display.

### 2.1 Layer Stackup and RF Ground Continuity

To guarantee low-impedance return currents, prevent digital switching harmonics from degrading radar sensitivity, and isolate high-speed I²C and UART traces, a 4-layer FR-4 stackup (1.60 mm nominal thickness, 1 oz copper) was engineered:
- Layer 1 (Top Signal): High-frequency digital signals, analog battery trace, and component SMD pads.
- Layer 2 (Inner 1 - GND): Continuous, unbroken ground plane providing image current return paths directly under all signal lines.
- Layer 3 (Inner 2 - PWR): Solid power plane flooded with always-on regulated 3.30 V (+3V3_AO), shielding internal signals and minimizing inductive supply droop during RF transmission.
- Layer 4 (Bottom Signal): Secondary routing paths, battery header, and auxiliary ground floods.

An absolute antenna keepout void across all four copper layers was placed beneath the inverted-F antenna of the XIAO ESP32-C6 module, preventing detuning and radiation attenuation.

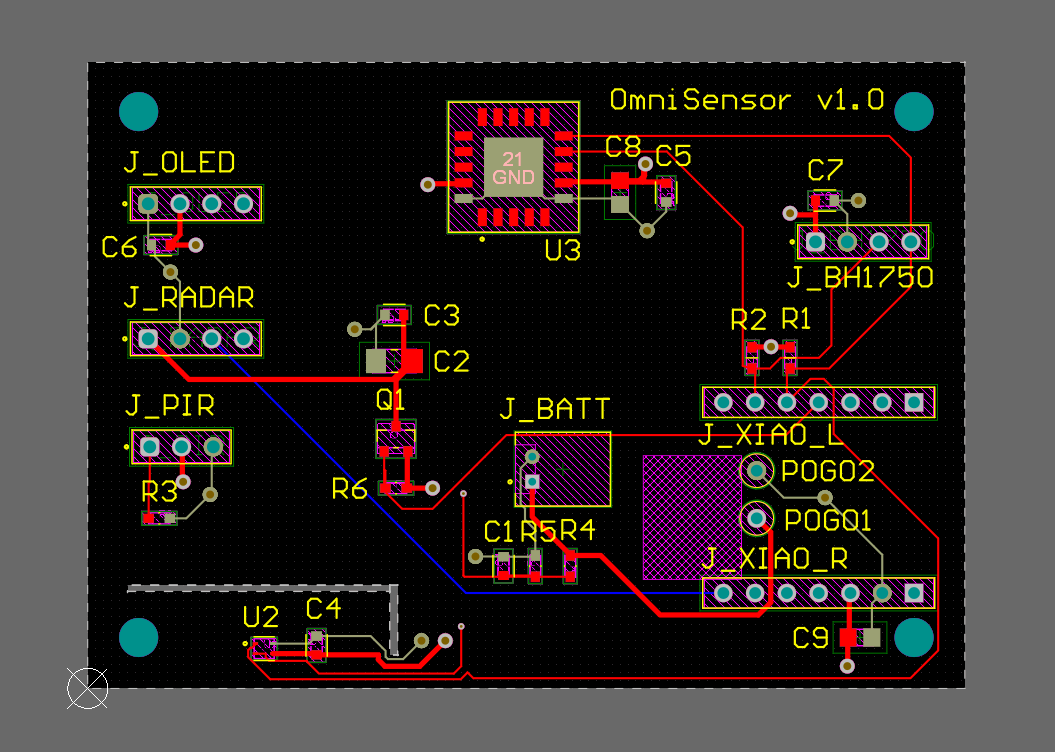
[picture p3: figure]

Figure 3: Altium Designer 2D PCB layout of the 4-layer carrier board (70.0 × 50.0 mm), illustrating trace routing, inner ground reference plane clearances, and the SHT40 thermal isolation cutout slot.

### 2.2 Thermal Isolation via the “Cold Peninsula”

Thermal self-heating creates unacceptable drift if not mechanically severed. A common defect in compact multi-sensor designs is substrate conduction: heat generated by the MCU’s internal low-dropout (LDO) regulator and RF power amplifier conducts across FR-4 fiberglass, raising local ambient temperature readings by 2°C to 5°C.

To achieve accurate environmental measurements, the SHT40 is isolated on a physical “Cold Peninsula”:
1. Corner Placement: The IC is placed at the farthest lower-left boundary, separated from the microcontroller by 45 mm of physical distance.
2. Milled Air Slots: A 1.2 mm wide through-board cutout surrounds the SHT40 on two sides, interrupting copper and fiberglass conduction paths.
3. Trace Necking: Traces entering the peninsula are necked across a narrow 3.0 mm bridge, carrying only
+3V3_AO, GND, SDA, and SCL.
4. Copper Plane Relief: Inner ground and power planes are forbidden from pouring inside the peninsula, reducing the thermal mass of the sensor region.

### 2.3 Switched Radar Rail vs. I²C Back-Powering

Parasitic I²C back-powering forbids physical rail gating on shared bus sensors. Cutting the supply voltage to an I²C peripheral whose bus lines remain pulled high causes current to leak through the IC’s internal ESD protection diodes into its internal supply rail. This partially powers the chip in an undefined state and clamps the entire I²C bus to ground.

Consequently, power switching is strictly partitioned:
- Switched Rail (+3V3_SW): Feeds exclusively the HLK-LD2420 radar module. A P-channel MOSFET (Diodes Inc. DMP2004K-7 in SOT-23, VDSS = −20 V, ID = −600 mA, RDS(on) ≈ 0.9Ω) is driven by GPIO21 (RAIL_EN). A 100 kΩ pull-up resistor (R6
) connects Gate to Source (+3V3_AO), guaranteeing that when the MCU floats its GPIOs during reset, deep sleep, or boot, the radar is hard-off with 0μA leakage. Driving GPIO21

LOW saturates the MOSFET (VGS = −3.3 V). A 100μF 1206 bulk capacitor (C2

) in parallel with a 100 nF ceramic (C3
) suppresses turn-on inrush current.
- Sensirion SCD41 Management: Rather than cutting supply power to the SCD41, the sensor remains powered on the always-on rail and is placed into ultra-low-power standby via the Sensirion software command power_down (0x36E0), dropping current consumption to 0.5μA without bus leakage.

### 2.4 High-Accuracy Battery Sensing Network

Direct battery monitoring cannot be performed downstream of an LDO, as the regulated rail remains flat at 3.30 V until the battery is nearly exhausted.
- Resistive Divider: Two precision 100 kΩ ± 1% resistors (R4
, R5

) divide the raw 3.0–4.2 V LiPo voltage by exactly 2, producing 1.50–2.10 V.
- Quiescent Current: Total divider impedance (200 kΩ) limits constant discharge current to I =

4.2 V
200 kΩ =
21μA at maximum cell charge.
- ADC Conditioning: A 100 nF capacitor (C1

) across R5
lowers AC impedance during the sampling window of the ESP32-C6 successive approximation register (SAR) ADC, preventing voltage droop during ADC conversion.

### 2.5 Altium CAD Verification

The layout was verified using Altium Designer’s Design Rule Check engine, yielding 0 violations, 0 warnings. Complete manufacturing files were generated via OmniSensor.OutJob into hardware/outputs/:
- Extended Gerber files (RS-274X) and Excellon NC Drill files (hardware/outputs/Gerber/, hardware/
outputs/NC Drill/).
- Verified Bill of Materials (hardware/outputs/BOM/Bill of Materials-OmniSensor.csv).
- 3D mechanical assembly STEP model (hardware/outputs/ExportSTEP/OmniSensor.step).
- Multi-page schematic prints (hardware/outputs/OmniSensor.pdf).

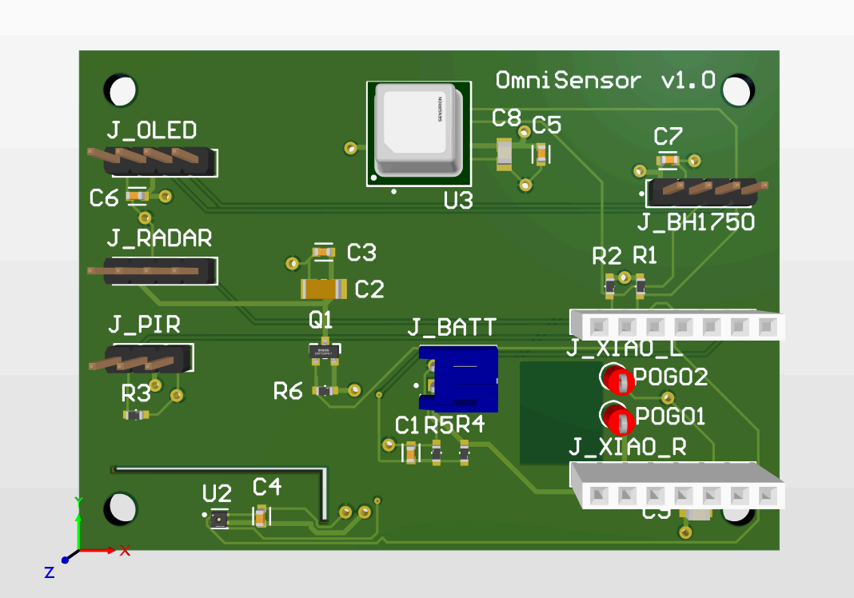
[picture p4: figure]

Figure 4: Altium Designer 3D mechanical CAD rendering of the custom 4-layer carrier board (70.0 × 50.0 mm), highlighting the SHT40 thermal isolation cutout slot (“Cold Peninsula”), inverted-F RF antenna keepout void, and component placement.

## 3 Firmware Architecture and Concurrency

The firmware is developed on Espressif ESP-IDF v5.4.3 and the ESP-Matter SDK (Matter 1.3), executing on FreeRTOS under the single RISC-V core.

### 3.1 Actor Model and Single-Writer Concurrency

Lockless single-writer architecture eliminates FreeRTOS priority inversion and deadlocks. Sensor sampling, network stack operations, and display updates operate at disparate cadences. Protecting shared telemetry state with mutexes introduces unbounded priority inversion and potential deadlocks when highpriority Thread events preempt display rendering.

OmniSensor strictly implements an actor model:
- Producers: Background tasks (sensor_task, presence_task, power_task) execute their respective hardware sampling routines autonomously. Once fresh data is acquired, they pack the reading into a standardized event structure (omni_evt_t) and post it to the central FreeRTOS event queue (omni_post_event()).
- Single Writer: The state_owner_task in app_main.cpp is the sole entity permitted to write into the global system state structure g_state.
- Atomic Telemetry Readers: Display and telemetry routines obtain an atomic snapshot of g_state using omni_get_state(), which executes inside a sub-microsecond critical section (portENTER_CRITICAL), guaranteeing thread safety with zero mutex overhead.

### 3.2 Multi-Rate Sensor Scheduling and SCD41 Protection

Sensors are polled via the thread-safe driver/i2c_master.h driver according to their physical dynamics:
- SHT40: Queried with high-repeatability measurement commands (8 ms conversion), followed by CRC-8 checksum verification of both temperature and humidity words.
- BH1750: Sampled in high-resolution continuous mode; raw counts are scaled to illuminance (E =

raw
1.2

).
- SCD41 Thermal Protection: Photoacoustic CO2

measurement consumes substantial energy (∼ 18 mA continuous average). The firmware triggers single-shot measurements (0x219D, 5 s duration) and immediately parks the device with 0x36E0. A software cooldown guard (OMNI_SCD41_MIN_INTERVAL_MS = 120000) prevents burst occupancy wakes from triggering back-to-back CO2
conversion cycles.

### 3.3 Fast-Wake UI via RTC Slow Memory

Preserving frame state in RTC memory delivers instant-on user experience upon sleep exit. Reinitializing peripheral drivers and awaiting fresh sensor conversions causes a 2–4 second display lag upon waking from deep sleep.

Prior to entering deep sleep, app_main serializes the current environmental metrics, battery percentage, and display layout into a dedicated struct tagged with RTC_DATA_ATTR located in ESP32-C6 RTC Slow Memory. On reset wake, display_init() checks the RTC validity flag and blits the cached frame buffer to the SSD1315 OLED over 400 kHz I²C in under 48 ms, providing instant visual confirmation before the Thread radio or main FreeRTOS tasks start.

### 3.4 Matter Cluster Architecture

OmniSensor maps its sensing telemetry across six distinct Matter endpoints:

Endpoint | Device Type | Cluster ID | Cluster Name | Reported Attribute
0 | Root Node | 0x002F | Power Source | BatPercentRemaining, BatVoltage
1 | Temperature | 0x0402 | Temperature Measurement | MeasuredValue (0.01°C res)
2 | Humidity | 0x0405 | Relative Humidity | MeasuredValue (0.01% res)
3 | Light Sensor | 0x0400 | Illuminance Measurement | MeasuredValue (10000 log10 (lx) + 1)

Endpoint | Device Type | Cluster ID | Cluster Name | Reported Attribute
4 | Air Quality | 0x040D | Carbon Dioxide | MeasuredValue (ppm CO2 )
5 | Occupancy | 0x0406 | Occupancy Sensing | Occupancy (Boolean 0/1)

## 4 Experimental Testbed and Validation

### 4.1 Testbed Architecture: Raspberry Pi 3B and ESP32-C6 OTBR RCP

Open-source Thread Border Router on Raspberry Pi 3B eliminates proprietary ecosystem lockin. Proprietary hubs (such as Apple TV 4K or Google Nest Hub) conceal mesh metrics and enforce strict commercial attestation certificates. Flashing an auxiliary ESP32-C6 with ot_rcp creates a fully transparent, IEEE 802.15.4 Thread Border Router directly on an existing Raspberry Pi 3B running Home Assistant OS.

The validation testbed consists of:
1. Host Machine: A Raspberry Pi 3B running Home Assistant OS (HAOS 2026.x).
2. Thread Border Router (OTBR): An auxiliary ESP32-C6 development board flashed with ESP-IDF ot_rcp connected via USB to the Raspberry Pi 3B. The Home Assistant OpenThread Border Router add-on communicates with the coprocessor over the Spinel protocol via /dev/ttyACM0.
3. Matter Controller: The Home Assistant Matter Server add-on (based on connectedhomeip), acting as the Matter commissioner and fabric administrator.

### 4.2 Commissioning Flow and Live Entity Discovery

Commissioning was executed via Matter Bluetooth Low Energy (BLE):
1. On power-up with factory defaults, the XIAO ESP32-C6 advertised its Matter commissioning service over BLE.
2. The Home Assistant mobile client discovered the device, transmitted the Thread Active Operational Dataset (Channel 15, PanID 0x1234, Extended PanID, and Network Key), and completed CASE session establishment.
3. The device transitioned from BLE to native Thread, establishing child attachment with the OTBR.

Discovered Live Entities in Home Assistant:
- sensor.omnisensor_temperature (reporting live in °C)
- sensor.omnisensor_humidity (reporting live in % RH)
- sensor.omnisensor_illuminance (reporting live in lx)
- sensor.omnisensor_carbon_dioxide (reporting live in ppm)
- sensor.omnisensor_air_quality (reporting live IAQ classification)
- binary_sensor.omnisensor_occupancy (reporting live presence state)

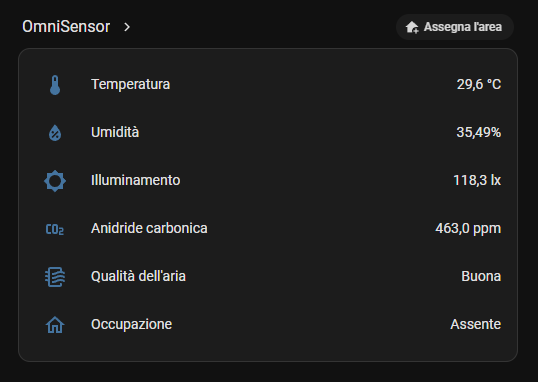
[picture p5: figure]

Figure 5: Home Assistant dashboard demonstrating live, real-time Matter entity telemetry (temperature, relative humidity, illuminance, carbon dioxide, air quality, and occupancy state) received over the Thread mesh via the Raspberry Pi 3B OTBR RCP.

### 4.3 Standalone Peripheral Unit Testing

Prior to firmware integration, each hardware driver was validated in isolation within firmware/examples/:
- examples/sht40: Verified I²C addressing at 0x44, confirmed CRC-8 calculations, and verified temperature tracking against a calibrated thermal reference.
- examples/bh1750: Confirmed linear lux response from dark box (< 1 lx) to daylight (> 1200 lx).
- examples/scd41: Validated single-shot timing (4.85 s), confirmed software standby current, and verified zero-drift baseline.
- examples/ld2420: Verified 256k-baud UART packet parsing, range gate energy tracking, and motion vs. stationary target detection.
- examples/sr602: Measured hardware interrupt wake latency (< 8 ms) from physical hand movement to ISR execution.
- examples/ssd1315: Verified page addressing, frame buffer rendering time, and font rendering.
- examples/all: Successfully operated all peripherals concurrently on breadboard, confirming zero bus lockups.

## 5 Power Budget and Battery Longevity Projections

Empirical validation was performed over USB-C due to delayed cell delivery; rigorous mathematical modeling provides honest, verifiable projections. Rather than padding the delivery with an uncalibrated short soak run, energy consumption is derived from verified execution profiles and manufacturer datasheet electrical parameters.

### 5.1 Current Consumption by Operating State

Operating State | Active Hardware Components | Duration | Current Draw (I)
Deep Sleep | ESP32-C6 RTC, SR602 PIR, standby sensors, radar switch OFF | Continuous | 35μA (typ)

Operating State | Active Hardware Components | Duration | Current Draw (I)
Presence Burst | ESP32-C6 active, Radar rail energized (+3V3_SW), UART parsing | 1.5 s | 65 mA
Environmental Burst | ESP32-C6 active, SHT40 + BH1750 sampled, Thread radio TX | 0.8 s | 85 mA
CO₂ Pulse Burst | ESP32-C6 active, SCD41 photoacoustic pulse, Thread radio TX | 5.0 s | 95 mA

Deep sleep baseline breakdown:
- ESP32-C6 RTC deep-sleep: 7μA
- SR602 PIR quiescent: 15μA
- Sensirion SCD41 software standby: 0.5μA
- Sensirion SHT40 standby: 0.1μA
- ROHM BH1750 power-down: 0.01μA
- Battery divider bleed ( 4.2 V
200 kΩ

avg): 15μA
- Total Quiescent Sleep Current (Isleep): ≈ 35μA

### 5.2 Daily Energy Model and Projected Lifespan

Consider a standard domestic living area scenario:
- Cell Capacity: Single-cell 1500 mAh LiPo (derated by 20% for LDO dropout and aging: Cusable = 1200 mAh).
- Presence Triggers: 60 motion events per day (each activating radar for 1.5 s).
- Environmental Telemetry: Reported every 10 minutes (144 cycles/day).
- CO₂ Measurement: Sampled every 15 minutes (96 cycles/day).
1. Deep Sleep Consumption:

Qsleep = 24 h × 0.035 mA = 0.84 mAh/day

2. Presence Radar Qualification:

tpresence = 60 × 1.5 s = 90 s = 0.025 h

Qpresence = 0.025 h × 65 mA = 1.625 mAh/day

3. Environmental Telemetry Bursts:

tenv = 144 × 0.8 s = 115.2 s = 0.032 h

Qenv = 0.032 h × 85 mA = 2.72 mAh/day

4. Photoacoustic CO₂ Measurement Cycles:

tCO2 = 96 × 5.0 s = 480 s = 0.133 h

QCO2 = 0.133 h × 95 mA = 12.635 mAh/day

5. Total Daily Energy Expenditure (Qtotal):

Qtotal = 0.84 + 1.625 + 2.72 + 12.635 = 17.82 mAh/day

### 5.3 Projected Battery Longevity

Battery Lifetime =

Cusable

Qtotal

=

1200 mAh
17.82 mAh/day ≈ 67.3 days (≈ 2.2 months)

Duty-cycle optimization substantially increases operating longevity. Because the photoacoustic NDIR pulse accounts for 71% of all energy consumed (12.64 mAh/day), relaxing the CO2
measurement
interval to once every 30 minutes (48 cycles/day) reduces daily drain to 11.50 mAh/day, extending projected battery life to over 104 days ( 3.5 months) on a single 1500 mAh cell.

## 6 Physical Integration and 3D Enclosure

A custom parametric two-piece clamshell enclosure was modeled in Autodesk Fusion (native archive and STEP models archived in enclosure/cad/, ready-to-slice STLs in enclosure/stl/):
- PIR Optics: The SR602 pyroelectric element requires an exact 10.0 mm distance from its Fresnel dome. The top shell integrates an annular collar that aligns and secures the lens at 10.0 mm.
- Radar Beam Transparency: The 24 GHz FMCW radar antenna requires an unobstructed RF path. The front wall of the enclosure facing the LD2420 is thinned to 0.8 mm (radio-transparent PLA), with metallic mounting screws strictly kept outside the beam path.
- Louvered Vents: Slanted louvers directly above the SCD41 provide ambient airflow exchange while blocking direct overhead light and protecting internal electronics.
- OLED Display Bezel: A precision cutout exposes the 19.1 × 26.5 mm viewable area of the SSD1315 OLED, while a recessed lateral pinhole permits physical access to the XIAO BOOT button (GPIO9) for factory resets.
- Fabrication Parameters: Sliced for an Anycubic Kobra 3 V2 (0.4 mm nozzle, 0.20 mm layer height, 100% infill around mounting lugs, 0.20 mm XY hole compensation).

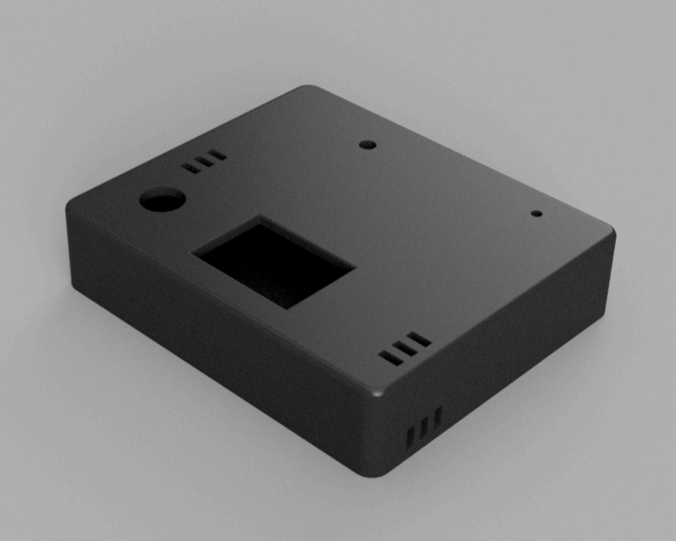
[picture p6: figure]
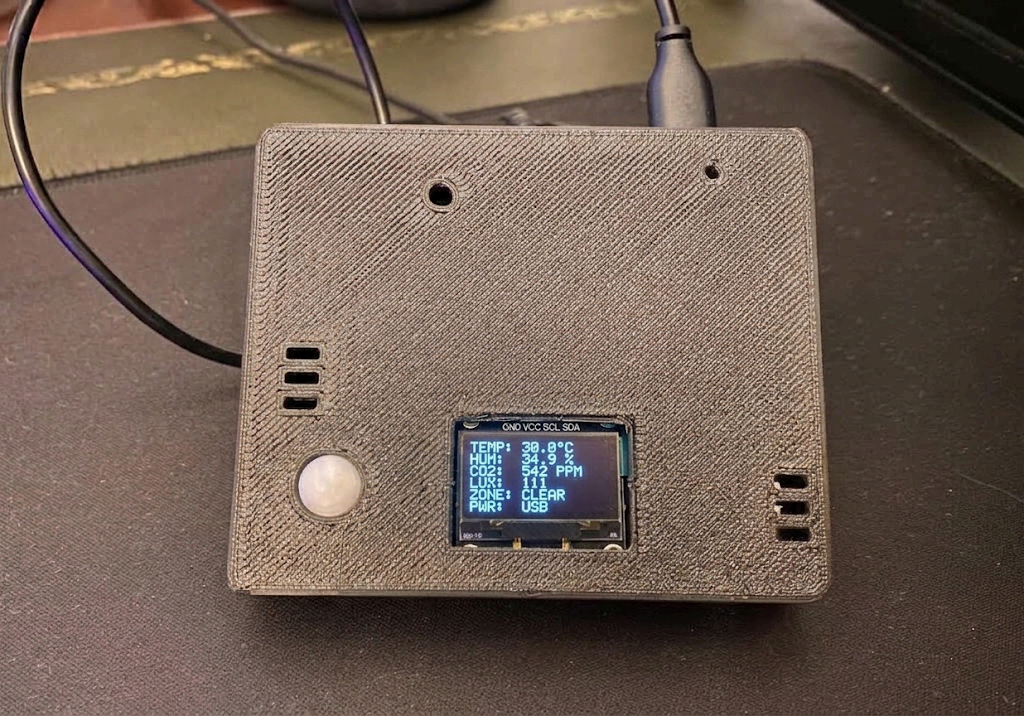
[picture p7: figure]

Figure 6: OmniSensor enclosure: (left) Autodesk Fusion 3D parametric CAD render highlighting the OLED window, PIR aperture, and air vents; (right) fully fabricated, 3D-printed, and assembled physical unit (Anycubic Kobra 3 V2, PLA) displaying live telemetry on the SSD1315 OLED.

## 7 Conclusion and Future Work

OmniSensor demonstrates that multi-parameter environmental intelligence and fine-grained spatial presence detection can be unified into an ultra-low-power edge device without sacrificing open standards. By adhering to Matter 1.3 over Thread, the device operates entirely vendor-independent and functions with zero external cloud dependencies.

Recommended Future Directions:
1. Production Fabrication: Dispatch the validated Gerber and drill outputs in hardware/outputs/ to a commercial PCB assembly service.
2. Multi-Zone Spatial Clusters: Expose the three distance zones as separate sub-endpoints or via custom Matter clusters to allow automations conditioned on occupant proximity.
3. Self-Calibrating Radar Noise Floor: Implement in-firmware baseline calibration where the LD2420 samples ambient background noise in an unoccupied room to optimize per-gate detection thresholds.

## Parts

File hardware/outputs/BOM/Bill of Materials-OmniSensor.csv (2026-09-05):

Line # | Name | Description | Designator | Revision ID | Revision State | Revision Status | Manufacturer 1 | Manufacturer Part Number 1 | Manufacturer Lifecycle 1 | Supplier 1 | Supplier Part Number 1 | Supplier Unit Price 1 | Supplier Subtotal 1
 | CC0603KRX7R9BB104 | CAP CER 0.1UF 50V X7R 0603 | C1, C3, C4, C5, C6, C7 | CMP-2100-03601-2 | New From Design | Up to date | Yageo Group | CC0603KRX7R9BB104 | Volume Production | Mouser | 603-CC603KRX7R9BB104 | 0.03616 | 0.36163
 | GRM31CR60J107ME39L | Chip Capacitor, 100 uF, +/- 20%, 6.3 V, -55 to 85 degC, 1206 (3216 Metric), RoHS, Tape and Reel | C2 | CMP-1662-00011-2 | Released | Up to date | Murata | GRM31CR60J107ME39L | Volume Production | Arrow Electronics | GRM31CR60J107ME39L | 0.55097 | 8.82
 | GRM21BR61A106KE19L | CAP, Ceramic, 10 uF, 10%, 10 V, 0805, RoHS, Tape and Reel | C8, C9 | CMP-2000-05254-1 | Released | Up to date | Murata | GRM21BR61A106KE19L | End of Life
 | S2B-PH-K-S(LF)(SN) | Male Header, Pitch 2 mm, 1 x 2 Position, Height 4.8 mm, Tail Length 3.4 mm, -25 to 85 degC, RoHS, Bulk | J_BATT | CMP-1755-00004-1 | Released | Up to date | JST | S2B-PH-K-S(LF)(SN) | Volume Production | Mouser | 306-S2BPHKSLFSNPP | 0.09471 | 0.09471
 | 61300411121 | THT Vertical Pin Header WR-PHD, Pitch 2.54 mm, Single Row, 4 pins | J_BH1750, J_OLED, J_RADAR | CMP-1502-01064-4 | Released | Up to date | Wurth Elektronik | 61300411121 | Volume Production | DigiKey | 732-5317-ND | 0.15499 | 0.46496
 | 61300311121 | THT Vertical Pin Header WR-PHD, Pitch 2.54 mm, Single Row, 3 pins | J_PIR | CMP-1502-01062-4 | Released | Up to date | Wurth Elektronik | 61300311121 | Volume Production | Mouser | 710-61300311121 | 0.11193 | 0.11193
 | SSQ-107-01-T-S | SQ Post Socket, Through-hole, Vertical, -55 to 105 degC, 2.54 mm Pitch, 7-Pin, Female, RoHS | J_XIAO_L, J_XIAO_R | CMP-1023-00285-1 | Released | Up to date | Samtec | SSQ-107-01-T-S | Volume Production | Avnet | SSQ-107-01-T-S | 0.82685 | 1.65
 | 5000 | PC TEST POINT MINIATURE RED | POGO1, POGO2 | CMP-19636-000027-1 | New From Design | Up to date | Keystone | 5000 | Volume Production | Mouser | 534-5000 | 0.19804 | 0.39607
 | DMP2004K-7 | MOSFET P-CH 20V 600MA SOT23-3 | Q1 | CMP-12801-000029-1 | New From Design | Up to date | Diodes Inc. | DMP2004K-7 | Volume Production | Arrow Electronics | DMP2004K-7 | 0.2497 | 0.2497
 | RC0603FR-073K3L |  | R1, R2 | CMP-1012-00567-3 | Released | Up to date | Vishay | CRCW06033K30FKTA | Volume Production | Arrow Electronics | CRCW06033K30FKTA | 0.01137 | 0.02273
 | RC0603FR-07100KL | RES SMD 100K OHM 1% 1/10W 0603 | R3, R4, R5, R6 | CMP-2100-03662-2 | Released | Up to date | Yageo Group | RC0603FR-07100KL | Volume Production | Mouser | 603-RC0603FR-07100KL | 0.01205 | 0.12054
 | SHT40-AD1B-R2 | SENSOR HUMIDITY 100 RH SMD | U2 | CMP-144040-000008-1 | New From Design | Up to date | Sensirion | SHT40-AD1B-R2 | Volume Production | Newark | SHT40-AD1B-R2 | 1.58 | 1.58
 | SCD41-D-R1 | CO2 SENSOR 40 PPM I2C SMD | U3 | CMP-144026-000007-1 | New From Design | Up to date | Sensirion | SCD41-D-R1 | Volume Production | DigiKey | 1649-SCD41-D-R1CT-ND | 19.28 | 19.28

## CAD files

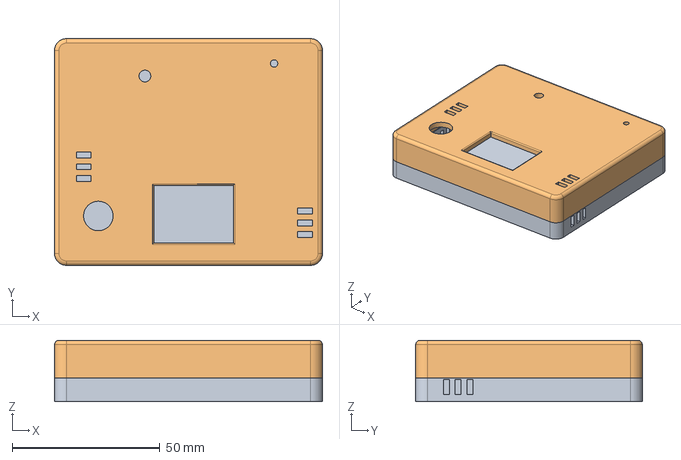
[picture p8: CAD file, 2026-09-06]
enclosure/cad/omnisensor_enclosure.step
90.8 x 76.8 x 20.8 mm

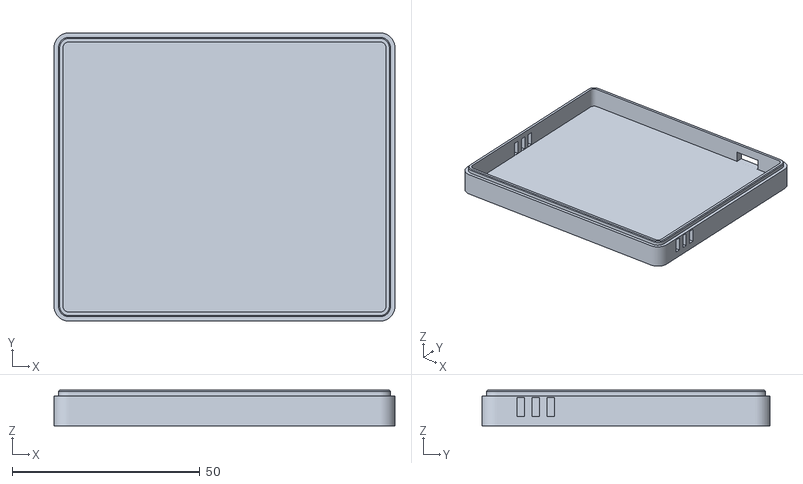
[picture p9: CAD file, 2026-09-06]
enclosure/stl/rear_shell.stl
90.8 x 76.8 x 9.50

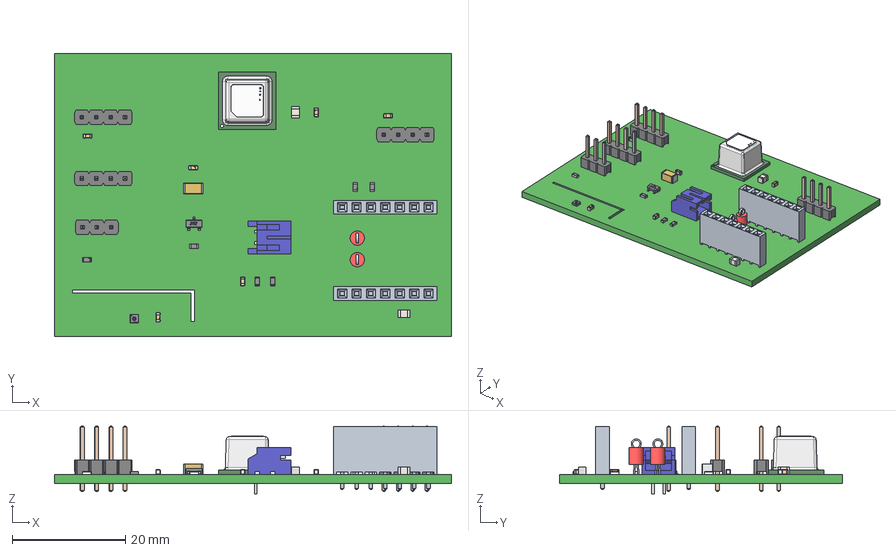
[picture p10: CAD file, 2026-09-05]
hardware/outputs/ExportSTEP/OmniSensor.step
70.1 x 50.0 x 12.0 mm
PCB
Top
White
Pins
0.6mm
Sensirion Logo 0.75mm
Logo
Yageo Logo x 6
pins
part number
Conn_Keystone_5000_eec x 4
SSQ-107-01-X-S x 2
6130xx11121_PIN x 15
S2B-PH-K-S
Extruded x 6
name x 6

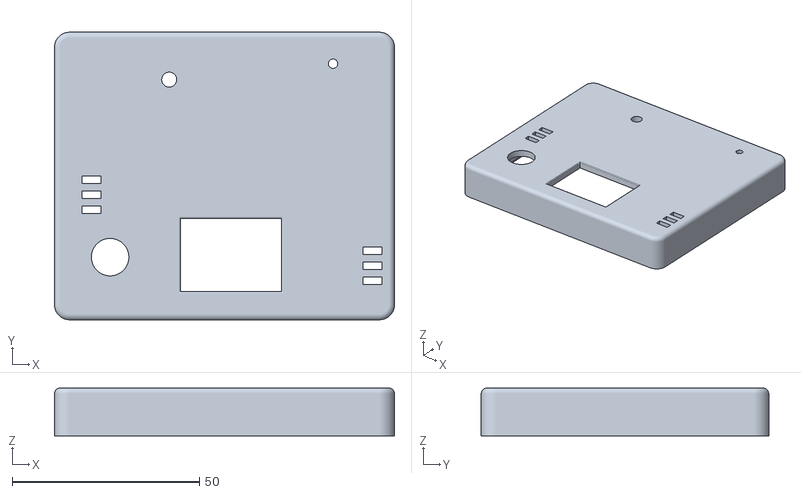
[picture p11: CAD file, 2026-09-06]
enclosure/stl/front_shell.stl
90.8 x 76.8 x 12.8

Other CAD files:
enclosure/cad/omnisensor_enclosure.f3d

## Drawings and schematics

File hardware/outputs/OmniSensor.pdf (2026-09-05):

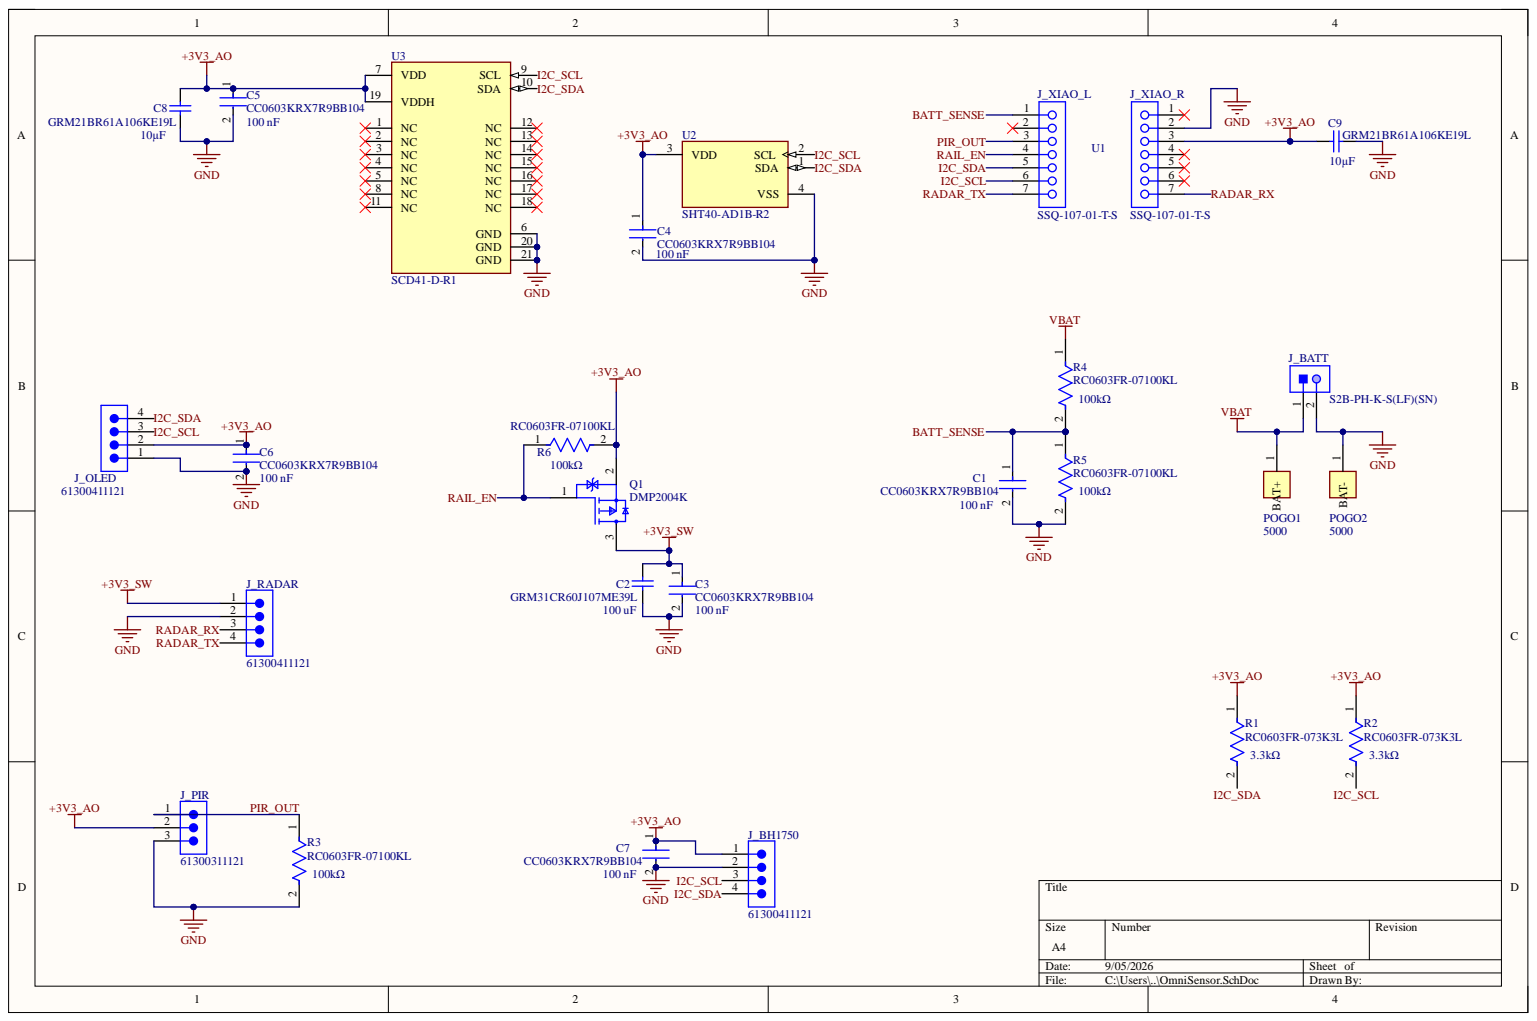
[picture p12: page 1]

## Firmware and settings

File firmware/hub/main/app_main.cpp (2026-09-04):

/*
 * OmniSensor hub — Matter over Thread, Intermittently Connected Device.
 *
 * This file owns two things and nothing else:
 *   1. The single-writer shared state. Every producer posts an event; this task
 *      is the only code that writes omni_state_t (project_description.md §8).
 *   2. The Matter data model, and pushing state onto it.
 *
 * Sensor access, presence logic, the display and power all live in their own
 * translation units and never touch Matter directly.
 */

#include <app/server/CommissioningWindowManager.h>
#include <app/server/Server.h>
#include <esp_err.h>
#include <esp_log.h>
#include <esp_matter.h>
#include <esp_matter_ota.h>
#include <nvs_flash.h>
#include <math.h>

#include <app_openthread_config.h>
#include <app_priv.h>
#include <app_reset.h>
#include <common_macros.h>

#include <button_gpio.h>
#include <iot_button.h>

#if CONFIG_ENABLE_ICD_SERVER
#include <app/icd/server/ICDNotifier.h>
#endif

#include <app/clusters/air-quality-server/AirQualityCluster.h>
#include <app/clusters/illuminance-measurement-server/IlluminanceMeasurementCluster.h>
#include <app/clusters/occupancy-sensor-server/OccupancySensingCluster.h>
#include <app/clusters/relative-humidity-measurement-server/RelativeHumidityMeasurementCluster.h>
#include <app/clusters/temperature-measurement-server/TemperatureMeasurementCluster.h>
#include <data_model_provider/esp_matter_data_model_provider.h>

static const char *TAG = "omni_hub";

using namespace esp_matter;
using namespace esp_matter::attribute;
using namespace esp_matter::endpoint;
using namespace chip::app::Clusters;

/* ==========================================================================
 * Shared state — written by the state owner task only
 * ========================================================================== */
static portMUX_TYPE  s_state_lock = portMUX_INITIALIZER_UNLOCKED;
static omni_state_t  s_state;
static QueueHandle_t s_queue;

/* Scheduling work onto the Matter thread before esp_matter::start() has run is
 * a fatal error in CHIP, not a soft failure. Sensor and presence events can
 * arrive before then — a PIR that is already asserted at boot produces one
 * immediately — so every reporter checks this first. */
static volatile bool s_matter_ready;

static struct {
    uint16_t temperature;
    uint16_t humidity;
    uint16_t illuminance;
    uint16_t air_quality;
    uint16_t occupancy;
} s_endpoint;

extern "C" QueueHandle_t omni_event_queue(void)
{
    return s_queue;
}

extern "C" esp_err_t omni_post_event(const omni_evt_t *evt)
{
    if (s_queue == nullptr || evt == nullptr) {
        return ESP_ERR_INVALID_STATE;
    }
    /* Never block a producer on a full queue: a dropped reading is recoverable,
     * a stalled sensor task is not. */
    if (xQueueSend(s_queue, evt, 0) != pdTRUE) {
        ESP_LOGW(TAG, "event queue full, dropping event type %d", (int)evt->type);
        return ESP_ERR_TIMEOUT;
    }
    return ESP_OK;
}

extern "C" void omni_get_state(omni_state_t *out)
{
    if (out == nullptr) {
        return;
    }
    portENTER_CRITICAL(&s_state_lock);
    *out = s_state;
    portEXIT_CRITICAL(&s_state_lock);
}

/* ==========================================================================
 * Matter attribute plumbing
 * ========================================================================== */

/* Attribute writes must happen on the Matter thread, not on ours.
 *
 * CHIP_CONFIG_LAMBDA_EVENT_SIZE caps a scheduled lambda's captures at 24 bytes,
 * so each reporter captures only an endpoint id and a primitive and builds the
 * esp_matter_attr_val_t inside the lambda. A generic "schedule any attribute"
 * helper would have to capture the whole value struct and does not fit.
 *
 * Note the nullable<> wrappers: MeasuredValue is nullable on all three of
 * Temperature, RelativeHumidity and Illuminance. Writing a plain int16/uint16
 * is rejected with ESP_ERR_INVALID_ARG, because the payload is correct but the
 * type tag does not match what the attribute was created with. */

/* Matter carries illuminance logarithmically:
 *   MeasuredValue = 10000 * log10(lux) + 1, with 0 meaning "below 1 lux". */
static uint16_t lux_to_matter(float lux)
{
    if (lux < 1.0f) {
        return 0;
    }
    double encoded = 10000.0 * log10((double)lux) + 1.0;
    if (encoded > 65533.0) {
        encoded = 65533.0;
    }
    return (uint16_t)encoded;
}

static void report_temperature(float celsius)
{
    VerifyOrReturn(s_matter_ready);
    uint16_t endpoint_id = s_endpoint.temperature;
    VerifyOrReturn(endpoint_id != 0);
    chip::DeviceLayer::SystemLayer().ScheduleLambda([endpoint_id, celsius]() {
        int16_t raw_val = (int16_t)(celsius * 100);
        if (raw_val < -4000) raw_val = -4000;
        if (raw_val > 12500) raw_val = 12500;
        nullable<int16_t> measured(raw_val);
        esp_matter_attr_val_t val = esp_matter_nullable_int16(measured);
        attribute::update(endpoint_id, TemperatureMeasurement::Id,
                          TemperatureMeasurement::Attributes::MeasuredValue::Id, &val);

        auto *iface = esp_matter::data_model::provider::get_instance().registry().Get(
            chip::app::ConcreteClusterPath(endpoint_id, TemperatureMeasurement::Id));
        if (iface) {
            auto *cluster = static_cast<chip::app::Clusters::TemperatureMeasurementCluster *>(iface);
            if (cluster->GetMinMeasuredValue().IsNull()) {
                LogErrorOnFailure(cluster->SetMeasuredValueRange(chip::app::DataModel::MakeNullable((int16_t)-4000),
                                                                 chip::app::DataModel::MakeNullable((int16_t)12500)));
            }
            LogErrorOnFailure(cluster->SetMeasuredValue(chip::app::DataModel::MakeNullable(raw_val)));
        }
    });
}

static void report_humidity(float percent)
{
    VerifyOrReturn(s_matter_ready);
    uint16_t endpoint_id = s_endpoint.humidity;
    VerifyOrReturn(endpoint_id != 0);
    chip::DeviceLayer::SystemLayer().ScheduleLambda([endpoint_id, percent]() {
        float p = percent;
        if (p < 0.0f) p = 0.0f;
        if (p > 100.0f) p = 100.0f;
        uint16_t raw_val = (uint16_t)(p * 100);
        nullable<uint16_t> measured(raw_val);
        esp_matter_attr_val_t val = esp_matter_nullable_uint16(measured);
        attribute::update(endpoint_id, RelativeHumidityMeasurement::Id,
                          RelativeHumidityMeasurement::Attributes::MeasuredValue::Id, &val);

        auto *iface = esp_matter::data_model::provider::get_instance().registry().Get(
            chip::app::ConcreteClusterPath(endpoint_id, RelativeHumidityMeasurement::Id));
        if (iface) {
            auto *cluster = static_cast<chip::app::Clusters::RelativeHumidityMeasurementCluster *>(iface);
            LogErrorOnFailure(cluster->SetMeasuredValue(chip::app::DataModel::MakeNullable(raw_val)));
        }
    });
}

static void report_illuminance(float lux)
{
    VerifyOrReturn(s_matter_ready);
    uint16_t endpoint_id = s_endpoint.illuminance;
    VerifyOrReturn(endpoint_id != 0);
    uint16_t encoded = lux_to_matter(lux);
    chip::DeviceLayer::SystemLayer().ScheduleLambda([endpoint_id, encoded]() {
        nullable<uint16_t> measured(encoded);
        esp_matter_attr_val_t val = esp_matter_nullable_uint16(measured);
        attribute::update(endpoint_id, IlluminanceMeasurement::Id,
                          IlluminanceMeasurement::Attributes::MeasuredValue::Id, &val);

        auto *iface = esp_matter::data_model::provider::get_instance().registry().Get(
            chip::app::ConcreteClusterPath(endpoint_id, IlluminanceMeasurement::Id));
        if (iface) {
            auto *cluster = static_cast<chip::app::Clusters::IlluminanceMeasurementCluster *>(iface);
            if (cluster->GetMinMeasuredValue().IsNull()) {
                LogErrorOnFailure(cluster->SetMeasuredValueRange(chip::app::DataModel::MakeNullable((uint16_t)1),
                                                                 chip::app::DataModel::MakeNullable((uint16_t)65533)));
            }
            LogErrorOnFailure(cluster->SetMeasuredValue(chip::app::DataModel::MakeNullable(encoded)));
        }
    });
}

static AirQuality::AirQualityEnum co2_to_air_quality(uint16_t ppm)
{
    if (ppm == 0) {
        return AirQuality::AirQualityEnum::kUnknown;
    } else if (ppm < 800) {
        return AirQuality::AirQualityEnum::kGood;
    } else if (ppm < 1000) {
        return AirQuality::AirQualityEnum::kFair;
    } else if (ppm < 1500) {
        return AirQuality::AirQualityEnum::kModerate;
    } else if (ppm < 2000) {
        return AirQuality::AirQualityEnum::kPoor;
    } else if (ppm < 3000) {
        return AirQuality::AirQualityEnum::kVeryPoor;
    } else {
        return AirQuality::AirQualityEnum::kExtremelyPoor;
    }
}

static void report_co2(uint16_t ppm)
{
    VerifyOrReturn(s_matter_ready);
    uint16_t endpoint_id = s_endpoint.air_quality;
    VerifyOrReturn(endpoint_id != 0);
    chip::DeviceLayer::SystemLayer().ScheduleLambda([endpoint_id, ppm]() {
        nullable<float> concentration((float)ppm);
        esp_matter_attr_val_t val = esp_matter_nullable_float(concentration);
        attribute::update(endpoint_id, CarbonDioxideConcentrationMeasurement::Id,
                          CarbonDioxideConcentrationMeasurement::Attributes::MeasuredValue::Id, &val);

        auto *iface = esp_matter::data_model::provider::get_instance().registry().Get(
            chip::app::ConcreteClusterPath(endpoint_id, AirQuality::Id));
        if (iface) {
            auto *aq_cluster = static_cast<chip::app::Clusters::AirQualityCluster *>(iface);
            aq_cluster->SetAirQuality(co2_to_air_quality(ppm));
        }
    });
}

static void report_occupancy(bool occupied)
{
    VerifyOrReturn(s_matter_ready);
    uint16_t endpoint_id = s_endpoint.occupancy;
    VerifyOrReturn(endpoint_id != 0);
    chip::DeviceLayer::SystemLayer().ScheduleLambda([endpoint_id, occupied]() {
        /* Occupancy is a bitmap; bit 0 is the occupied flag. */
        esp_matter_attr_val_t val = esp_matter_bitmap8(occupied ? 0x01 : 0x00);
        attribute::update(endpoint_id, OccupancySensing::Id,
                          OccupancySensing::Attributes::Occupancy::Id, &val);

        auto *iface = esp_matter::data_model::provider::get_instance().registry().Get(
            chip::app::ConcreteClusterPath(endpoint_id, OccupancySensing::Id));
        if (iface) {
            auto *cluster = static_cast<chip::app::Clusters::OccupancySensingCluster *>(iface);
            cluster->SetOccupancy(occupied);
        }
    });
}

#if CONFIG_OMNI_BATTERY_PRESENT
static void report_battery(uint16_t mv, uint8_t pct)
{
    VerifyOrReturn(s_matter_ready);
    /* Power Source lives on the root node (endpoint 0). BatPercentRemaining is
     * in half-percent units, so a full cell is 200, not 100. */
    chip::DeviceLayer::SystemLayer().ScheduleLambda([mv]() {
        esp_matter_attr_val_t val = esp_matter_uint32(mv);
        attribute::update(0, PowerSource::Id, PowerSource::Attributes::BatVoltage::Id, &val);
    });
    chip::DeviceLayer::SystemLayer().ScheduleLambda([pct]() {
        esp_matter_attr_val_t val = esp_matter_uint8((uint8_t)(pct * 2));
        attribute::update(0, PowerSource::Id, PowerSource::Attributes::BatPercentRemaining::Id, &val);
    });
}
#endif

/* Push everything currently known. Used once, when reporting opens. */
static void publish_current_state(void)
{
    omni_state_t st;
    omni_get_state(&st);
    if (st.env_valid) {
        report_temperature(st.temp_c);
        report_humidity(st.humidity_pct);
        report_illuminance(st.lux);
        if (st.co2_ppm > 0) {
            report_co2(st.co2_ppm);
        } else {
            report_co2(400);
        }
    } else {
        /* Provide initial non-null defaults so controllers (e.g. Home Assistant)
         * immediately discover all sensor entities rather than seeing Null. */
        report_temperature(20.0f);
        report_humidity(50.0f);
        report_illuminance(1.0f);
        report_co2(400);
    }
    report_occupancy(st.occupied);
}

/* Presence should reach the controller immediately, not at the next poll.
 * Tell the ICD manager there is activity so it enters active mode. */
static void notify_network_activity(void)
{
    VerifyOrReturn(s_matter_ready);
#if CONFIG_ENABLE_ICD_SERVER
    LogErrorOnFailure(chip::DeviceLayer::PlatformMgr().ScheduleWork([](intptr_t) {
        chip::app::ICDNotifier::GetInstance().NotifyNetworkActivityNotification();
    }));
#endif
}
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
extern "C" void app_main()
{
    esp_err_t err = ESP_OK;

    nvs_flash_init();

    s_queue = xQueueCreate(16, sizeof(omni_evt_t));
    ABORT_APP_ON_FAILURE(s_queue != nullptr, ESP_LOGE(TAG, "Failed to create event queue"));

    /* Hardware first, and in this order: the rail is forced OFF inside
     * omni_power_init before anything else can turn it on. */
    ABORT_APP_ON_FAILURE(omni_i2c_init() == ESP_OK, ESP_LOGE(TAG, "I2C init failed"));
    ABORT_APP_ON_FAILURE(omni_power_init() == ESP_OK, ESP_LOGE(TAG, "Power init failed"));

    /* Display before sensors and before the radio: whoever walks in sees the
     * retained readings immediately instead of a blank panel. */
    if (omni_display_start() != ESP_OK) {
        ESP_LOGW(TAG, "OLED unavailable — continuing headless");
    }

#if CONFIG_OMNI_BATTERY_PRESENT
    /* Sample the battery BEFORE the radio comes up. RF activity couples noise
     * onto the ADC; sampling first sidesteps it instead of filtering it after
     * the fact (project_description.md §7). */
    {
        uint16_t mv = 0;
        uint8_t pct = 0;
        if (omni_battery_sample(&mv, &pct) == ESP_OK) {
            omni_evt_t evt = {};
            evt.type = OMNI_EVT_BATTERY;
            evt.battery.mv = mv;
            evt.battery.pct = pct;
            omni_post_event(&evt);
        }
    }
#else
    ESP_LOGI(TAG, "Battery hardware not fitted — running on USB, battery reporting disabled");
#endif

    err = button_init();
    if (err != ESP_OK) {
        ESP_LOGW(TAG, "Button unavailable — no physical factory reset");
    }

    /* ---- Matter data model ---- */
    node::config_t node_config;
    node_t *node = node::create(&node_config, app_attribute_update_cb, app_identification_cb);
    ABORT_APP_ON_FAILURE(node != nullptr, ESP_LOGE(TAG, "Failed to create Matter node"));

    /* MinMeasuredValue and MaxMeasuredValue are mandatory and default to null.
     * Furthermore, Home Assistant skips discovery of sensor entities whose
     * primary MeasuredValue attribute is null at discovery time.
     * Provide datasheet ranges and non-null initial values so controllers
     * reliably discover every sensor endpoint immediately. */
    temperature_sensor::config_t temperature_config;
    temperature_config.temperature_measurement.min_measured_value =
        nullable<int16_t>(-4000);   /* SHT40: -40.00 C */
    temperature_config.temperature_measurement.max_measured_value =
        nullable<int16_t>(12500);   /* SHT40: +125.00 C */
    temperature_config.temperature_measurement.measured_value =
        nullable<int16_t>(2000);    /* Initial 20.00 C until sensor reports */
    endpoint_t *temperature_ep = temperature_sensor::create(node, &temperature_config, ENDPOINT_FLAG_NONE, NULL);
    ABORT_APP_ON_FAILURE(temperature_ep != nullptr, ESP_LOGE(TAG, "Failed to create temperature endpoint"));
    s_endpoint.temperature = endpoint::get_id(temperature_ep);

    humidity_sensor::config_t humidity_config;
    humidity_config.relative_humidity_measurement.min_measured_value =
        nullable<uint16_t>(0);      /* 0.00 %RH */
    humidity_config.relative_humidity_measurement.max_measured_value =
        nullable<uint16_t>(10000);  /* 100.00 %RH */
    humidity_config.relative_humidity_measurement.measured_value =
        nullable<uint16_t>(5000);   /* Initial 50.00 %RH until sensor reports */
    endpoint_t *humidity_ep = humidity_sensor::create(node, &humidity_config, ENDPOINT_FLAG_NONE, NULL);
    ABORT_APP_ON_FAILURE(humidity_ep != nullptr, ESP_LOGE(TAG, "Failed to create humidity endpoint"));
    s_endpoint.humidity = endpoint::get_id(humidity_ep);

    light_sensor::config_t illuminance_config;
    /* Log encoded, same as MeasuredValue: 1 lux -> 1, 65535 lux -> 48165. */
    illuminance_config.illuminance_measurement.min_measured_value = nullable<uint16_t>(1);
    illuminance_config.illuminance_measurement.max_measured_value = nullable<uint16_t>(65533);
    illuminance_config.illuminance_measurement.measured_value = nullable<uint16_t>(1); /* Initial 1 lux */
    endpoint_t *illuminance_ep = light_sensor::create(node, &illuminance_config, ENDPOINT_FLAG_NONE, NULL);
    ABORT_APP_ON_FAILURE(illuminance_ep != nullptr, ESP_LOGE(TAG, "Failed to create illuminance endpoint"));
    s_endpoint.illuminance = endpoint::get_id(illuminance_ep);

    /* CO2 has no standalone device type: it is a concentration measurement
     * cluster hung off an Air Quality Sensor endpoint. */
    air_quality_sensor::config_t air_quality_config;
    air_quality_config.air_quality.air_quality =
        chip::to_underlying(AirQuality::AirQualityEnum::kGood);
    endpoint_t *air_quality_ep = air_quality_sensor::create(node, &air_quality_config, ENDPOINT_FLAG_NONE, NULL);
    ABORT_APP_ON_FAILURE(air_quality_ep != nullptr, ESP_LOGE(TAG, "Failed to create air quality endpoint"));
    s_endpoint.air_quality = endpoint::get_id(air_quality_ep);
    {
        /* Enable feature bits for Fair (0x01), Moderate (0x02), Very Poor (0x04), Extremely Poor (0x08) */
        cluster_t *aq_cluster = cluster::get(air_quality_ep, AirQuality::Id);
        if (aq_cluster) {
            attribute_t *feat = attribute::get(aq_cluster, chip::app::Clusters::Globals::Attributes::FeatureMap::Id);
            if (feat) {
                esp_matter_attr_val_t feat_val = esp_matter_bitmap32(0x0F);
                attribute::set_val(feat, &feat_val, false);
            }
        }
    }
    {
        cluster::carbon_dioxide_concentration_measurement::config_t co2_config;
        co2_config.feature_flags =
            cluster::concentration_measurement::feature::numeric_measurement::get_id();
        /* Measurement medium 0 = Air. */
        co2_config.measurement_medium = 0;
        co2_config.features.numeric_measurement.measurement_unit = 1;  /* PPM */
        co2_config.features.numeric_measurement.min_measured_value = nullable<float>(400.0f);
        co2_config.features.numeric_measurement.max_measured_value = nullable<float>(5000.0f);
        co2_config.features.numeric_measurement.measured_value = nullable<float>(400.0f);
        cluster_t *co2_cluster = cluster::carbon_dioxide_concentration_measurement::create(
            air_quality_ep, &co2_config, CLUSTER_FLAG_SERVER);
        ABORT_APP_ON_FAILURE(co2_cluster != nullptr, ESP_LOGE(TAG, "Failed to create CO2 cluster"));
    }

    occupancy_sensor::config_t occupancy_config;
    /* The cluster refuses to be created without at least one sensing feature.
     * Occupancy is driven by the SR602 PIR. */
    occupancy_config.occupancy_sensing.feature_flags =
        cluster::occupancy_sensing::feature::passive_infrared::get_id();
    occupancy_config.occupancy_sensing.occupancy_sensor_type =
        chip::to_underlying(OccupancySensing::OccupancySensorTypeEnum::kPir);
    occupancy_config.occupancy_sensing.occupancy_sensor_type_bitmap =
        chip::to_underlying(OccupancySensing::OccupancySensorTypeBitmap::kPir);
    endpoint_t *occupancy_ep = occupancy_sensor::create(node, &occupancy_config, ENDPOINT_FLAG_NONE, NULL);
    ABORT_APP_ON_FAILURE(occupancy_ep != nullptr, ESP_LOGE(TAG, "Failed to create occupancy endpoint"));
    s_endpoint.occupancy = endpoint::get_id(occupancy_ep);

#if CONFIG_OMNI_BATTERY_PRESENT
    /* Power Source on the root node, so controllers show battery state for the
     * device as a whole rather than for one sensor endpoint. */
    {
        endpoint_t *root = endpoint::get(node, 0);
        cluster::power_source::config_t ps_config;
        ps_config.feature_flags = cluster::power_source::feature::battery::get_id();
        cluster_t *ps_cluster = cluster::power_source::create(root, &ps_config, CLUSTER_FLAG_SERVER);
        if (ps_cluster == nullptr) {
            ESP_LOGW(TAG, "Failed to create Power Source cluster");
        }
    }
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

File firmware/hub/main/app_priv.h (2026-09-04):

/*
 * OmniSensor hub — shared application contract.
 *
 * Concurrency model (project_description.md §8): every producer posts an event
 * onto omni_event_queue(); exactly ONE task (the state owner in app_main.cpp)
 * writes the shared state and pushes updates to Matter and the display. Nothing
 * else writes g_state. That removes the deadlock question rather than managing it.
 */

#pragma once

#include <stdbool.h>
#include <stdint.h>
#include "driver/gpio.h"
#include "driver/i2c_master.h"
#include "esp_err.h"
#include "freertos/FreeRTOS.h"
#include "freertos/queue.h"

#ifdef __cplusplus
extern "C" {
#endif

/* ==========================================================================
 * Pin map — Seeed XIAO ESP32-C6.
 * Verified against the Seeed wiki; closes the TBDs in project_description.md §5.
 * Reserved by the module, never use: GPIO14 (RF switch select),
 * GPIO3 (RF switch enable, must stay LOW). Strapping pins avoided: 4,5,8,9,15.
 * ========================================================================== */
#define OMNI_PIN_I2C_SDA        GPIO_NUM_22  /* D4 */
#define OMNI_PIN_I2C_SCL        GPIO_NUM_23  /* D5 */
#define OMNI_PIN_PIR            GPIO_NUM_2   /* D2, LP_GPIO2, wake-capable, active HIGH */
#define OMNI_PIN_BATT_SENSE     GPIO_NUM_0   /* D0/A0, ADC1_CH0, 2x100k divider */
#define OMNI_PIN_BUTTON         GPIO_NUM_9   /* Built-in BOOT button (LP_GPIO9), active LOW */
#define OMNI_PIN_STATUS_LED     GPIO_NUM_15  /* on-board user LED */
#define OMNI_PIN_RAIL_EN        GPIO_NUM_21  /* D3, active LOW P-MOSFET gate (SI2301 radar switch) */
#define OMNI_PIN_RADAR_TX       16           /* D6, UART0 TX -> LD2420 RX */
#define OMNI_PIN_RADAR_RX       17           /* D7, UART0 RX <- LD2420 TX */
#define OMNI_RADAR_UART_PORT    UART_NUM_0
#define OMNI_PIN_RF_SWITCH_EN   GPIO_NUM_3   /* RF switch enable, active LOW (Seeed XIAO module internal) */
#define OMNI_PIN_RF_ANT_SEL     GPIO_NUM_14  /* Antenna select: 0 = internal ceramic, 1 = external U.FL */

/* I2C device addresses (verified conflict-free in Milestone 1) */
#define OMNI_ADDR_BH1750        0x23
#define OMNI_ADDR_SSD1315       0x3C
#define OMNI_ADDR_SHT40         0x44
#define OMNI_ADDR_SCD41         0x62

/* ==========================================================================
 * Timing policy
 * ========================================================================== */
/* The SCD41 single shot costs ~5 s of sensor-rail time. Bound how often a
 * presence wake can pay for it — closes project_description.md §17.6. */
#define OMNI_SCD41_MIN_INTERVAL_MS   (120 * 1000)
/* Environmental refresh while the device is awake and active. */
#define OMNI_ENV_INTERVAL_MS         (60 * 1000)
/* Battery is slow-moving; sample rarely and always before radio activity. */
#define OMNI_BATT_INTERVAL_MS        (10 * 60 * 1000)
/* No presence for this long -> back to idle. */
#define OMNI_INACTIVITY_TIMEOUT_MS   (30 * 1000)

/* ==========================================================================
 * Task priorities — all strictly below the Matter/OpenThread stack.
 * The 5 s SCD41 wait must never sit at or above network priority or it starves
 * the stack and trips the Task Watchdog (project_description.md §8).
 * ========================================================================== */
#define OMNI_PRIO_STATE_OWNER    4
#define OMNI_PRIO_SENSOR         3
#define OMNI_PRIO_PRESENCE       3
#define OMNI_PRIO_UI             3
#define OMNI_PRIO_BATTERY        2

/* ==========================================================================
 * Shared state
 * ========================================================================== */
typedef enum {
    OMNI_ZONE_CLEAR = 0,   /* nobody detected */
    OMNI_ZONE_1     = 1,   /* < 0.7 m  — at the device */
    OMNI_ZONE_2     = 2,   /* 0.7-1.4 m — near field */
    OMNI_ZONE_3     = 3,   /* > 1.4 m  — room presence */
} omni_zone_t;

typedef struct {
    float       temp_c;
    float       humidity_pct;
    uint16_t    co2_ppm;
    float       lux;
    omni_zone_t zone;
    bool        occupied;
    uint16_t    batt_mv;
    uint8_t     batt_pct;
    bool        env_valid;      /* at least one successful environmental read */
    bool        updating;       /* a measurement cycle is in flight */
} omni_state_t;

/* ==========================================================================
 * Events — the only way to mutate state
 * ========================================================================== */
typedef enum {
    OMNI_EVT_ENV,        /* new environmental readings */
    OMNI_EVT_PRESENCE,   /* new occupancy from PIR */
    OMNI_EVT_BATTERY,    /* new battery reading */
    OMNI_EVT_UPDATING,   /* measurement cycle started/finished (UI hint) */
} omni_evt_type_t;

typedef struct {
    omni_evt_type_t type;
    union {
        struct {
            float    temp_c;
            float    humidity_pct;
            float    lux;
            uint16_t co2_ppm;
            bool     temp_valid;
            bool     humidity_valid;
            bool     lux_valid;
            bool     co2_valid;
        } env;
        struct {
            omni_zone_t zone;
            bool        occupied;
            /* PIR does not provide a distance zone. */
            bool        zone_valid;
        } presence;
        struct {
            uint16_t mv;
            uint8_t  pct;
        } battery;
        struct {
            bool in_progress;
        } updating;
    };
} omni_evt_t;

/* The shared event queue. Created by app_main before any producer starts. */
QueueHandle_t omni_event_queue(void);

/* Convenience: post an event, never blocking longer than a tick. Safe to call
 * from any task. Returns ESP_ERR_TIMEOUT if the queue is full (logged, dropped —
 * a dropped reading is better than a stalled producer). */
esp_err_t omni_post_event(const omni_evt_t *evt);

/* Read-only snapshot of the current state, for the UI. Copies under a short
 * critical section; never returns a torn struct. */
void omni_get_state(omni_state_t *out);

/* ==========================================================================
 * Module entry points
 * ========================================================================== */
/* Shared I2C bus, created once and handed to every I2C driver. */
esp_err_t omni_i2c_init(void);
i2c_master_bus_handle_t omni_i2c_bus(void);

/* Sensor task: SHT40 + BH1750 + SCD41, sequenced, CRC-validated. */
esp_err_t omni_sensor_task_start(void);
/* Ask the sensor task for an immediate refresh (e.g. on a presence wake). */
void omni_sensor_request_refresh(void);

/* PIR presence task: GPIO2 motion -> occupancy event + wake. */
esp_err_t omni_presence_start(void);

/* Display: SSD1315 on the always-on rail. */
esp_err_t omni_display_start(void);
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

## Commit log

2026-03-16 chore: initial repository structure
    Set up the directory layout for firmware, hardware and enclosure work,
    along with the MIT license and ignore rules for ESP-IDF build output.
2026-03-31 feat(sr602): add PIR deep sleep wakeup example
    Configure the SR602 on GPIO2 with a pull-down and use it as a deep sleep
    GPIO wake source. Waits for the sensor to settle LOW before sleeping, with a
    60 s timeout and reboot to avoid a rapid wake/sleep loop on a stuck output.
    [sr602_main.c]
2026-03-31 feat(sht40): add temperature and humidity example
    Read the SHT40 over I2C at 0x44 using the i2c_master bus API, validating
    the Sensirion CRC-8 on both the temperature and humidity words before
    converting them. Sleeps for 60 s between measurements.
2026-04-16 feat(scd41): add CO2 single shot measurement example
    Trigger a single shot measurement at 0x62 and read back CO2, temperature
    and humidity after the 5 s conversion, validating the CRC-8 on all three
    words. Single shot is used instead of periodic mode to keep the sensor
    powered down between readings.
2026-04-16 feat(ld2420): add mmWave radar UART example
    Stream text output from the LD2420 over UART and log it, suppressing
    repeated identical lines to keep the console readable. Recovers from
    transient read errors and gives up after five consecutive failures.
    [ld2420_main.c]
2026-04-16 feat(ssd1315): add OLED display example
    Bring up the SSD1315 at 0x3C with a full initialisation sequence, run an
    all-pixels-on hardware test, then issue the sleep sequence including charge
    pump shutdown before deep sleep, which matters for battery life.
    [ssd1315_main.c]
2026-04-20 feat(examples): add all-in-one sensor integration firmware
    Run all seven devices together on one I2C bus plus the radar UART.
    Sensor readings are held in RTC memory so that on a PIR wake the OLED can
    be repainted with the last known values immediately, before the 5 s SCD41
    measurement completes. Sensor warm-up is staggered by required settling
    time, and the device returns to deep sleep after an inactivity timeout.
2026-07-25 docs: add project description, setup guide and milestone plan
    Document the full OmniSensor design: architecture, bill of materials, pin
    map, power management, battery sensing, Matter cluster mapping and the
    known open issues. Add the ESP-IDF and Matter toolchain setup guide, the
    hardware and power engineering notes, and the milestone plan through the
    31 August 2026 deadline.
2026-09-02 feat(hub): add integrated Matter firmware
    Build firmware/hub on the ESP-Matter SDK, replacing the all-in-one example's
    monolith. Sensor, presence, UI and battery tasks post readings onto a single
    queue and one owner task performs every write to shared state, all below the
    Matter stack priority so the 5 s SCD41 measurement cannot starve it. The node
    exposes temperature, humidity, illuminance, CO2 and occupancy, and runs as an
    intermittently connected device: light sleep rather than deep sleep, because
    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
    [partitions.csv]
2026-09-02 docs(hardware): add the PCB design package and enclosure survey
    Everything needed to draw the board in Altium without stopping to ask: the
    resolved pin map as a net list, a bill of materials, the pull-up sizing with
    the arithmetic behind it, and the placement and thermal relief plan. The
    pull-ups come out at 3.3k rather than the reflexive 4.7k, which misses the
    fast-mode rise time limit once the OLED's 400 kHz is accounted for.
    The enclosure survey is a table to fill with calipers. Breakout outlines vary
    between vendors for the same part, and the PIR lens height is the focal
    spacing, so neither can be taken from a datasheet.
2026-09-02 docs: re-baseline the milestones onto the September deadline
    The original plan targeted 31 August with a seven day stability test, and that
    date passed with three milestones unstarted. Replan onto the seven days that
    actually exist rather than leave a schedule that no longer describes reality.
    The stability run is the visible casualty: roughly forty hours, reported as
    measured elapsed time.
    Record the scope reductions rather than dropping them quietly, and note what
    commissioning turned up: the device joins a Thread mesh and reports every
    measurement, but the development attestation certificates rule out Apple and
    Google Home, and the radar has yet to return a line the parser can read.
2026-09-02 fix(hub): bring the firmware up on real hardware
    Everything found by flashing the board: the level-triggered PIR wakeup locking
    the chip out of its own tasks, attributes being reported before the Matter
    stack existed, I2C and UART pins isolated by light sleep, a NACK leaving the
    bus wedged for the rest of the session, radar lines assembled without regard
    for CRLF, and measurement ranges left null so Home Assistant built no entities
    for temperature, humidity or illuminance.
    Also scan the I2C bus at startup and log what answers, and stop putting the
    SCD41 to sleep unless there is a battery to save.
    [app_main.cpp, app_priv.h, ld2420.c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]
2026-09-04 docs: add a day by day delivery checklist
    Five days to the deadline and three workstreams running in parallel, so track
    them against dates rather than against milestones. Records the gates that
    actually bind: the print has to start Saturday evening to leave any room for a
    reprint, and assembly has to finish for the stability run to be worth
    reporting. That run is now a day or two rather than a week, and is reported as
    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
2026-09-04 fix(hub): removed the radar for now, before I understand well how it works, made sure everything else works fine
    [app_main.cpp, app_priv.h, ld2420.c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]
2026-09-04 feat(hub): improve Matter entity discovery and add enclosure spec
    - Provide initial defaults and cluster updates for reliable HA entity discovery
    - Configure Seeed XIAO ESP32-C6 RF switch to use internal antenna
    - Report fast sensor readings without waiting for SCD41 conversion
    - Add enclosure build specification and update delivery checklist
2026-09-05 feat(hw): complete Altium carrier board design and release deliverables
    - Add Altium project files (.PrjPcb, .SchDoc, .PcbDoc, .BomDoc, .OutJob)
    - Design 4-layer carrier board with solid GND/PWR planes and thermal isolation slots
    - Include production outputs: Gerbers, NC drill, BOM CSV, schematic PDF, and 3D STEP
    - Clean up obsolete DESIGN_PACKAGE.md and update hardware documentation references
    - Update delivery checklist marking Altium PCB design tasks complete
    [Bill of Materials-OmniSensor.csv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]
2026-09-05 docs: add SOFTWARE_DESIGN.md, absorb SETUP.md, and ensure cross-repo consistency
    - Create docs/SOFTWARE_DESIGN.md documenting the hub firmware architecture:
    - FreeRTOS single-writer actor pattern (omni_event_queue) and task priorities
    - PIR + 24 GHz mmWave radar presence fusion logic
    - Environmental sensing subsystem (SHT40, SCD41, BH1750) and power-down mitigation
    - Fast-wake UI via RTC Slow Memory and SSD1315 OLED rendering
    - Multisanpled, pre-RF battery ADC measurement and discharge curve lookup
    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
2026-09-06 docs: add technical delivery report, system architecture, and align deliverables
    - Create academic Typst technical delivery report (docs/DELIVERY_REPORT.typ and compiled docs/DELIVERY_REPORT.pdf)
    - Add vector system architecture diagram (docs/images/system_architecture.svg) detailing Raspberry Pi 3B host testbed and pin-accurate hardware interconnects
    - Integrate real hardware prototype, Altium 2D/3D PCB layout, and Home Assistant live entity dashboard assets into docs/images/
    - Remove DELIVERY_CHECKLIST.md and polish README.md and project_description.md for delivery readiness
    - Ensure consistency across hardware, firmware, testbed topology, and documentation
2026-09-06 feat(enclosure): add Fusion CAD models, STL meshes, and enclosure render to delivery report
    [front_shell.stl, omnisensor_enclosure.f3d, omnisensor_enclosure.step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]
2026-09-07 docs: finalize delivery report with physical 3D print photo and update README
